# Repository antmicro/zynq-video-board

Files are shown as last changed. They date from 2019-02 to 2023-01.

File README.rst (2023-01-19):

================
Zynq Video Board
================

Copyright (c) 2018-2023 `Antmicro <https://www.antmicro.com>`_



Overview
========

This repository contains open hardware design files required to build the Zynq Video Board.
The board was designed as a custom carrier board for `Enclustra Mars SoC Modules <https://www.enclustra.com/en/products/system-on-chip-modules>`_.
It has been tested with `Mars ZX2 <https://www.enclustra.com/en/products/system-on-chip-modules/mars-zx2/>`_ and `Mars ZX3 <https://www.enclustra.com/en/products/system-on-chip-modules/mars-zx3/>`_ with the `Xilinx Zynq 70xx <https://www.xilinx.com/products/silicon-devices/soc/zynq-7000.html>`_ All Programmable SoC devices.

It can be used for interfacing MIPI CSI compatible image sensors.
It can also act as a simple evaluation kit for educational purposes.

Key features
============

* SO-DIMM connector supporting Enclustra Mars family
* Gigabit Ethernet RJ45 connector
* Micro SD connector
* USB 2.0 hub with two downstream ports exposed
* HDMI output interface
* Debug micro USB connector (supporting serial console and JTAG)
* JTAG connector supporting Xiling Platform Cable
* 2x MIPI CSI-2 camera interfaces (2 lanes) exposed on FPC connector
* onboard D-PHY receiver circuitry connected to the FPGA fabric
* 2x Digilent Pmod (TM) connectors for external accessories

The PCB project files were prepared in Altium Designer 14.1.

Getting started
===============

The board can be produced and assembled using the provided design files.
Please take a look at the mechanical layers for more information regarding the PCB stackup recommended for fabrication.
It is recommended to use a 12V 2A DC supply to power the board.
By default the device boots from an SD card.
The boot mode could be changed into booting from QSPI flash by removing the ``R7`` resistor and assembling ``R8``.

Preparing the software
----------------------

The Zynq Video Board is compatible with Enclustra Mars modules which are natively supported by the `Enclustra Build Environment <https://github.com/enclustra-bsp/bsp-xilinx>`_ (EBE) which is developed by Antmicro for Enclustra.
Please refer to the EBE documentation and Zynq Video Board schematics in order to prepare the software that could support your hardware configuration.
Also, please note that Mars ZX2 and Mars ZX3 differ in FPGA ball assignment so they require different constraint files for bitstream generation.

Debug UART connection
---------------------

Most of the debug messages are provided through the serial console.
The board is equipped with a multichannel FTDI chip offering both JTAG and UART interfaces to the host PC.
Please refer to the schematic sheets for more details.
After connecting the micro USB debug port to the host PC you should see four new ``/dev/ttyUSBx`` devices in your system.
The default debug UART channel is accessible through ``/dev/ttyUSB2`` (assuming that there are no other FTDI units connected to your PC).
The default baudrate for serial debug connection is 115200 baud with 8-bit transmission, 1 stop bit and with no flow control.

License
=======

`Apache-2.0 <LICENSE>`_

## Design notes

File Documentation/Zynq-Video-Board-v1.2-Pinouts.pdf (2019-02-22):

This document describes Zynq Video Board Rev.1.2 connectors' pinouts.

# General purpose buttons and LEDs

There are several buttons and LEDs which usage can be configured by the user. The table below shows their Mars ZX2 module and Zynq chip pin and ball assignment.

LED pin assignment

PCB desi gnator | ZX2 module pin (SO-DIMM) | ZX2 module signal name | Zynq-702 0 ball | FPGA pin name
LED1 | 44 | IO_B34_L8_W14_P | W14 | IO_L8P_34
LED2 | 46 | IO_B34_L8_Y14_N | Y14 | IO_L8N_34
LED3 | 48 | IO_B34_L6_P14_P | P14 | IO_L6P_34
LED4 | 50 | IO_B34_L6_VREF_R14_N | R14 | IO_L6N_VREF_34
LED5 | 54 | IO_B34_L5_T14_P | T14 | IO_L5P_34
LED6 | 56 | IO_B34_L5_T15_N | T15 | IO_L5N_34
LED7 | 69 | IO_B34_L22_W18_P | W18 | IO_L22P_34
LED8 | 71 | IO_B34_L22_W19_N | W19 | IO_L22N_34

General purpose buttons pin assignment

PCB desi gnator | ZX2 module pin (SO-DIMM) | ZX2 module signal name | Zynq-702 0 ball | FPGA pin name
SW1.U7 | 148 | IO_MIO48_B13_L11_SRCC_U7 | B12 | PS_MIO48
SW2.U10 | 152 | IO_MIO50_B13_L12_MRCC_T9 | B13 | PS_MIO50
SW3.V7 | 154 | IO_MIO51_B13_L12_U10 | B9 | PS_MIO51
SW4.T9 | 150 | IO_MIO49_B13_L11_V7 | C12 | PS_MIO49

Note: PCB button designators do not match Mars ZX2 signal names (see table).

# JTAG connector pinout

JTAG pin description

Signal name | Pin | Pin | Signal name
GND | 1 | 2 | +3V3
GND | 3 | 4 | JTAG_TMS
GND | 5 | 6 | JTAG_TCK
GND | 7 | 8 | JTAG_TDO
GND | 9 | 10 | JTAG_TDI
GND | 11 | 12 | NC
GND | 13 | 14 | SRST_RDYN

# Digilent Pmod connectors

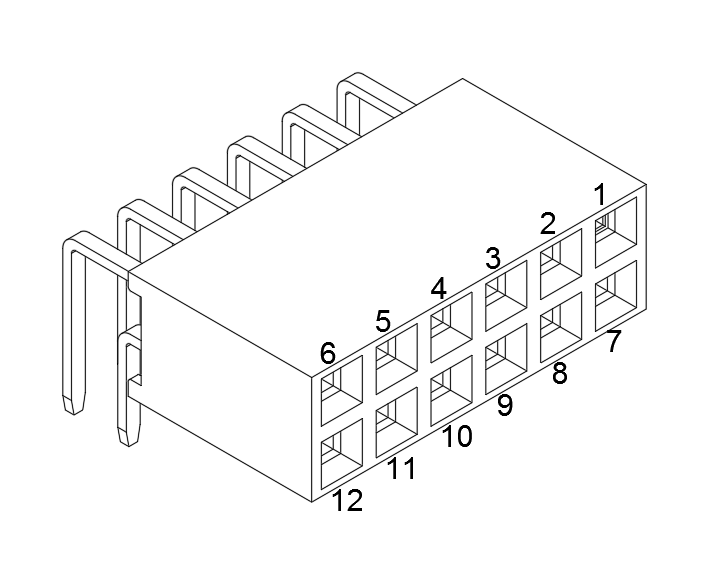
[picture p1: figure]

Digilent Pmod J6 connector pinout

Pin number | ZX2 module pin (SO-DIMM) | ZX2 module signal name | Zynq-70 20 ball | FPGA pin name
1 | 64 | IO_B34_L24_P15_P | P15 | IO_L24P_34
2 | 66 | IO_B34_L24_P16_N | P16 | IO_L24N_34
3 | 74 | IO_B34_L16_V20_P | V20 | IO_L16P_34
4 | 76 | IO_B34_L16_W20_N | W20 | IO_L16N_34
5 | GND | --- | --- | ---
6 | +3V3 | --- | --- | ---
7 | 68 | IO_B34_L23_N17_P | N17 | IO_L23P_34
8 | 70 | IO_B34_L23_P18_N | P18 | IO_L23N_34
9 | 78 | IO_B34_L15_T20_P | T20 | IO_L15P_34
10 | 80 | IO_B34_L15_U20_N | U20 | IO_L15N_34
11 | GND | --- | --- | ---
12 | +3V3 | --- | --- | ---

Digilent Pmod J7 connector pinout

Pin number | ZX2 module pin (SO-DIMM) | ZX2 module signal name | Zynq-70 20 ball | FPGA pin name
1 | 43 | IO_B34_L13_MRCC_N18_P | N18 | IO_L13P_MRCC_34
2 | 45 | IO_B34_L13_MRCC_P19_N | P19 | IO_L13N_MRCC_34
3 | 55 | IO_B34_L10_V15_P | V15 | IO_L10P_34
4 | 57 | IO_B34_L10_W15_N | W15 | IO_L10N_34
5 | GND | --- | --- | ---
6 | +3V3 | --- | --- | ---
7 | 49 | IO_B34_L14_SRCC_N20_P | N20 | IO_L14P_SRCC_34
8 | 51 | IO_B34_L14_SRCC_P20_N | P20 | IO_L14N_SRCC_34
9 | 59 | IO_B34_L7_Y16_P | Y16 | IO_L7P_34
10 | 61 | IO_B34_L7_Y17_N | Y17 | IO_L7N_34
11 | GND | --- | --- | ---
12 | +3V3 | --- | --- | ---

# MIPI-CSI connector pinout

The Zynq Video Board supports two 2-lane CSI-MIPI interfaces broken-out on FPC connector.

MIPI CSI connector pinout

Pin nu mber | ZVB signal name | ZX2 m odule pin (S O-DIM M) ZX2 module signal name | | Zynq-7 020 ball | FPGA pin name
1 | +5V0 | --- | --- | --- | ---
2 | +5V0 | --- | --- | --- | ---
3 | +3V3 | --- | --- | --- | ---
4 | +3V3 | --- | --- | --- | ---
5 | NC | --- | --- | --- | ---
6 | NC | --- | --- | --- | ---
7 | NC | --- | --- | --- | ---
8 | NC | --- | --- | --- | ---
9 | I2C_1_SCL_2V8 | 84 | IO_B35_L23_M14_P | M14 | IO_L23P_35
10 | I2C_1_SDA_2V8 | 86 | IO_B35_L23_M15_N | M15 | IO_L23N_35
11 | I2C_0_SCL_2V8 | 97 | IO_B35_L10_AD11_K19_P | K19 | IO_L10P_AD11P_35
12 | I2C_0_SDA_2V8 | 99 | IO_B35_L10_AD11_J19_N | J19 | IO_L10N_AD11N_35
13 | NC | --- | --- | --- | ---

14 | NC | --- | --- | --- | ---
15 | NC | --- | --- | --- | ---
16 | NC | --- | --- | --- | ---
17 | NC | --- | --- | --- | ---
18 | GPIO | 134 | IO_B35_L6_VREF_F17_N | F17 | IO_L6N_VREF_35
19 | NC | --- | --- | --- | ---
20 | NC | --- | --- | --- | ---
21 | GND | --- | --- | --- | ---
22 | CSI1_CLK_P | --- | --- | --- | ---
23 | CSI1_CLK_N | --- | --- | --- | ---
24 | GND | --- | --- | --- | ---
25 | CSI1_D0_P | --- | --- | --- | ---
26 | CSI1_D0_N | --- | --- | --- | ---
27 | CSI1_D1_P | --- | --- | --- | ---
28 | CSI1_D1_N | --- | --- | --- | ---
29 | NC | --- | --- | --- | ---
30 | NC | --- | --- | --- | ---
31 | NC | --- | --- | --- | ---
32 | NC | --- | --- | --- | ---
33 | GND | --- | --- | --- | ---
34 | NC | --- | --- | --- | ---
35 | NC | --- | --- | --- | ---
36 | GND | --- | --- | --- | ---
37 | NC | --- | --- | --- | ---
38 | NC | --- | --- | --- | ---
39 | GND | --- | --- | --- | ---
40 | CSI2_CLK_P | --- | --- | --- | ---
41 | CSI2_CLK_N | --- | --- | --- | ---
42 | GND | --- | --- | --- | ---
43 | CSI2_D0_P | --- | --- | --- | ---
44 | CSI2_D0_N | --- | --- | --- | ---
45 | CSI2_D1_P | --- | --- | --- | ---
46 | CSI2_D1_N | --- | --- | --- | ---
47 | NC | --- | --- | --- | ---
48 | NC | --- | --- | --- | ---
49 | NC | --- | --- | --- | ---
50 | NC | --- | --- | --- | ---

# Testpad list

Testpad list

Designator | | | Side | Description
GND | top | GND
TP1 | top | CAM1_PWDN signal
TP4 | top | CAM2_PWDN signal
TP5 | bottom | VOUT_1V8 signal
TP6 | bottom | Mars ZX2 SO-DIMM pin 123
TP7 | bottom | Mars ZX2 SO-DIMM pin 65
TP11 | bottom | GND

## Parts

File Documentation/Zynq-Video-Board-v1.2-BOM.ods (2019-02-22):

Bill of Materials
Project: | Zynq Video Board
Revision: | 1.2
Variant: | None
Creation Date: | 2/22/2019
Print Date: | 2019/02/22
Value | Footprint | Designator | Description | Manufacturer | Part Symbol | Quantity
2u2 | 0603 | C1 | MLCC SMT Capacitor 2u2F 0603 | TDK | C1608X5R1V225K080AC | 1
2u2 | 0603 | C2 | MLCC SMT Capacitor 2u2F 0603 | TDK | C1608X5R1V225K080AC | 1
100n | 0402 | C3 | MLCC SMT Capacitor 100nF 0402 | MULTICOMP | MC0402X104M100CT | 1
100n | 0402 | C4 | MLCC SMT Capacitor 100nF 0402 | MULTICOMP | MC0402X104M100CT | 1
2n2 | 0402 | C5 | MLCC SMT Capacitor 2n2 0402 | KEMET | C0402C222J3GACTU | 1
22u | 0805 | C6 | MLCC SMT Capacitor 22uF 0805 | MULTICOMP | MC0805X226M6R3CT | 1
22u | 0805 | C7 | MLCC SMT Capacitor 22uF 0805 | MULTICOMP | MC0805X226M6R3CT | 1
100n | 0402 | C11 | MLCC SMT Capacitor 100nF 0402 | MULTICOMP | MC0402X104M100CT | 1
100n | 0402 | C12 | MLCC SMT Capacitor 100nF 0402 | MULTICOMP | MC0402X104M100CT | 1
1n5 | 0402 | C13 | MLCC SMT Capacitor 1.5 nF 0402 | WURTH ELEKTRONIK | 885012205007 | 1
22u | 0805 | C14 | MLCC SMT Capacitor 22uF 0805 | MULTICOMP | MC0805X226M6R3CT | 1
22u | 0805 | C15 | MLCC SMT Capacitor 22uF 0805 | MULTICOMP | MC0805X226M6R3CT | 1
10n | 0402 | C16 | MLCC SMT Capacitor 10nF 0402 | AVX | 04025G103ZAT2A | 1
10n | 0402 | C17 | MLCC SMT Capacitor 10nF 0402 | AVX | 04025G103ZAT2A | 1
1u | 0603 | C18 | MLCC SMT Capacitor 1u 0603 | MULTICOMP | MC0603X105M6R3CT | 1
100n | 0402 | C19 | MLCC SMT Capacitor 100nF 0402 | MULTICOMP | MC0402X104M100CT | 1
100n | 0402 | C20 | MLCC SMT Capacitor 100nF 0402 | MULTICOMP | MC0402X104M100CT | 1
100n | 0402 | C21 | MLCC SMT Capacitor 100nF 0402 | MULTICOMP | MC0402X104M100CT | 1
22u | 0805 | C22 | MLCC SMT Capacitor 22uF 0805 | MULTICOMP | MC0805X226M6R3CT | 1
22u | 0805 | C23 | MLCC SMT Capacitor 22uF 0805 | MULTICOMP | MC0805X226M6R3CT | 1
100n | 0402 | C24 | MLCC SMT Capacitor 100nF 0402 | MULTICOMP | MC0402X104M100CT | 1
1u | 0603 | C25 | MLCC SMT Capacitor 1u 0603 | MULTICOMP | MC0603X105M6R3CT | 1
18p | 0402 | C26 | MLCC SMT Capacitor 18pF 0402 | KEMET | C0402C180J5GACAUTO | 1
18p | 0402 | C27 | MLCC SMT Capacitor 18pF 0402 | KEMET | C0402C180J5GACAUTO | 1
100n | 0402 | C28 | MLCC SMT Capacitor 100nF 0402 | MULTICOMP | MC0402X104M100CT | 1
100n | 0402 | C29 | MLCC SMT Capacitor 100nF 0402 | MULTICOMP | MC0402X104M100CT | 1
100n | 0402 | C30 | MLCC SMT Capacitor 100nF 0402 | MULTICOMP | MC0402X104M100CT | 1
100n | 0402 | C31 | MLCC SMT Capacitor 100nF 0402 | MULTICOMP | MC0402X104M100CT | 1
4u7 | 0603 | C32 | MLCC SMT Capacitor 4u7 0603 | MULTICOMP | MC0603X475K6R3CT | 1
100n | 0402 | C33 | MLCC SMT Capacitor 100nF 0402 | MULTICOMP | MC0402X104M100CT | 1
100n | 0402 | C34 | MLCC SMT Capacitor 100nF 0402 | MULTICOMP | MC0402X104M100CT | 1
100n | 0402 | C35 | MLCC SMT Capacitor 100nF 0402 | MULTICOMP | MC0402X104M100CT | 1
100n | 0402 | C37 | MLCC SMT Capacitor 100nF 0402 | MULTICOMP | MC0402X104M100CT | 1
100n | 0402 | C38 | MLCC SMT Capacitor 100nF 0402 | MULTICOMP | MC0402X104M100CT | 1
100n | 0402 | C39 | MLCC SMT Capacitor 100nF 0402 | MULTICOMP | MC0402X104M100CT | 1
4u7 | 0603 | C40 | MLCC SMT Capacitor 4u7 0603 | MULTICOMP | MC0603X475K6R3CT | 1
100n | 0402 | C41 | MLCC SMT Capacitor 100nF 0402 | MULTICOMP | MC0402X104M100CT | 1
100n | 0402 | C42 | MLCC SMT Capacitor 100nF 0402 | MULTICOMP | MC0402X104M100CT | 1
100n | 0402 | C43 | MLCC SMT Capacitor 100nF 0402 | MULTICOMP | MC0402X104M100CT | 1
4u7 | 0603 | C44 | MLCC SMT Capacitor 4u7 0603 | MULTICOMP | MC0603X475K6R3CT | 1
100n | 0402 | C45 | MLCC SMT Capacitor 100nF 0402 | MULTICOMP | MC0402X104M100CT | 1
18p | 0402 | C46 | MLCC SMT Capacitor 18pF 0402 | KEMET | C0402C180J5GACAUTO | 1
18p | 0402 | C47 | MLCC SMT Capacitor 18pF 0402 | KEMET | C0402C180J5GACAUTO | 1
100n | 0402 | C48 | MLCC SMT Capacitor 100nF 0402 | MULTICOMP | MC0402X104M100CT | 1
100n | 0402 | C49 | MLCC SMT Capacitor 100nF 0402 | MULTICOMP | MC0402X104M100CT | 1
1u | 0603 | C50 | MLCC SMT Capacitor 1u 0603 | MULTICOMP | MC0603X105M6R3CT | 1
100n | 0402 | C51 | MLCC SMT Capacitor 100nF 0402 | MULTICOMP | MC0402X104M100CT | 1
100n | 0402 | C52 | MLCC SMT Capacitor 100nF 0402 | MULTICOMP | MC0402X104M100CT | 1
1u | 0603 | C53 | MLCC SMT Capacitor 1u 0603 | MULTICOMP | MC0603X105M6R3CT | 1
100n | 0402 | C54 | MLCC SMT Capacitor 100nF 0402 | MULTICOMP | MC0402X104M100CT | 1
1u | 0603 | C55 | MLCC SMT Capacitor 1u 0603 | MULTICOMP | MC0603X105M6R3CT | 1
100n | 0402 | C56 | MLCC SMT Capacitor 100nF 0402 | MULTICOMP | MC0402X104M100CT | 1
100n | 0402 | C57 | MLCC SMT Capacitor 100nF 0402 | MULTICOMP | MC0402X104M100CT | 1
2u2 | 0603 | C58 | MLCC SMT Capacitor 2u2F 0603 | TDK | C1608X5R1V225K080AC | 1
SMAJ12A | DO-214AA | D1 | DIODE, TVS, 12V, 400W | BOURNS | SMAJ12A | 1
1N4148WS | SOD-323 | D2 | Diode small signal | ON SEMICONDUCTOR | 1N4148WS | 1
BAV70LT3G | SOT-23 | D3 | Dual switching diode, common cathode | ON SEMICONDUCTOR | BAV70LT3G | 1
TPD2E009DRTR | SOT-3 | D4 | ESD Suppressors 2-CH | TEXAS INSTRUMENTS | TPD2E009DRTR | 1
TPD6E05U06 | TPD6E05U06_PASS | D5 | ESD Suppressors 6-CH Pass through layout | TEXAS INSTRUMENTS | TPD6E05U06RVZR | 1
TPD4E05U06 | TPD4E05U06_PASS | D7 | ESD Suppressors 4-CH | TEXAS INSTRUMENTS | TPD4E05U06DQAR | 1
TPD4E05U06 | TPD4E05U06_PASS | D9 | ESD Suppressors 4-CH | TEXAS INSTRUMENTS | TPD4E05U06DQAR | 1
TPD4E05U06 | TPD4E05U06_PASS | D10 | ESD Suppressors 4-CH | TEXAS INSTRUMENTS | TPD4E05U06DQAR | 1
TPD4E05U06 | TPD4E05U06_PASS | D11 | ESD Suppressors 4-CH | TEXAS INSTRUMENTS | TPD4E05U06DQAR | 1
TPD6E05U06 | TPD6E05U06_PASS | D12 | ESD Suppressors 6-CH Pass through layout | TEXAS INSTRUMENTS | TPD6E05U06RVZR | 1
KPT-1608SGC | LED0603 | D13 | LED Green 0603 case | KINGBRIGHT | KPT-1608SGC | 1
KPT-1608SGC | LED0603 | DBG | LED Green 0603 case | KINGBRIGHT | KPT-1608SGC | 1
3A | 0603 | F1 | Fuse, Surface Mount, SinglFuse SF-0603FP Series, 3 A, 32 VDC, Fast Acting, 0603 | BOURNS | SF-0603FP300-2 | 1
MX-22-23-2021 | molex_2223-2021 | FAN | Pinhead connector with key | MOLEX | 022232021 A-6373-02A222 | 1
TLV73328PDBVT | SOT23-5N | IC1 | Capacitor-Free, 300-mA, Low-Dropout Regulator with Foldback Current Limit for Portable Devices | TEXAS INSTRUMENTS | TLV73328PDBVT | 1
NCP3170BDR2G | SOIC-8 | IC2 | DC-DC buck (step-down), reg., 4.5V-18Vin, Vou 1.25V-5V/3A, 1 MHz, SOIC-8 | ON SEMICONDUCTOR | NCP3170BDR2G | 1
NCP3170BDR2G | SOIC-8 | IC4 | DC-DC buck (step-down), reg., 4.5V-18Vin, Vou 1.25V-5V/3A, 1 MHz, SOIC-8 | ON SEMICONDUCTOR | NCP3170BDR2G | 1
MIC2026-1YM | SOIC-8 | IC5 | Power Load Distribution Switch IC, Active High, 2 Outputs, 5.5 V in, 900 mA, 0.09 ohm, SOIC-8 | MICROCHIP | MIC2026-1YM | 1
USB2422 | QFN24 | IC6 | The USB2422-I/MJ is a 2-port USB 2.0 high-speed Hub Controller IC with two downstream ports for embedded USB solutions. | MICROCHIP | USB2422-I/MJ | 1
TPD12S016PWR | TSOP65P640X120-24L | IC7 | TPD12S016PWR is a single-chip High Definition Multimedia Interface (HDMI) | TEXAS INSTRUMENTS | TPD12S016PWR | 1
FT4232HQ | FT2232HQ | IC8 | FTDI FT4232HQ-R Interface Bridges, USB to UART, MPSSE, 1.62 V, 1.98 V, QFN, 64 Pins, -40 °C | FTDI | FT4232HQ-R | 1
NTB0104BQ | DHVQFN14 | IC9 | 4 bit voltage level translator - no pullups | NXP | NTB0104BQ | 1
NTB0104BQ | DHVQFN14 | IC10 | 4 bit voltage level translator - no pullups | NXP | NTB0104BQ | 1
NTB0104BQ | DHVQFN14 | IC11 | 4 bit voltage level translator - no pullups | NXP | NTB0104BQ | 1
NTS0104BQ | DHVQFN14 | IC12 | 4 bit voltage level translator - pullups | NXP | NTS0104BQ | 1
TCA9554A | DBQ0016A | IC13 | Remote 8bit I2C SMBus I/O expander | TEXAS INSTRUMENTS | TCA9554A | 1
RM24C128DS-LTAI-B | TSSOP-8 | IC14 | EEPROM with UID and OTP registers. | Adesto | RM24C128DS-LTAI-B | 1
TLV73333PDBVT | SOT23-5N | IC15 | Capacitor-Free, 300-mA, Low-Dropout Regulator with Foldback Current Limit for Portable Devices | TEXAS INSTRUMENTS | TLV73328PDBVT | 1
6A | 1101M2S3AQE2 | J1 | single-pole double-throw (SPDT) PC mount vertical Miniature Slide Switch with right angle through-hole termination | C&K | 1101M2S3AQE2 | 1
 | DC_SOCKET | J2 |  | MULTICOMP | MJ-179PH | 1
 | T_MMMC_896-43-008-90-000000 | J3 | 8-way 2-port USB 2.0 type-A Stacked Connector with gold-plated copper alloy contacts. | AMPHENOL | 72309-8014BLF | 1
68715014522 | 68715014522_FLIPPED | J5 | 0.50mm SMT ZIF Horizontal Bottom Contact WR-FPC | WURTH ELEKTRONIK | 68715014522 | 1
SSW-106-02-G-D-RA | SSW-106-02-G-D-RA | J6 | Board-To-Board Connector, Right Angle, 2.54 mm, 12 Contacts, Receptacle, SSW Series, Through Hole | SAMTEC | SSW-106-02-G-D-RA | 1
SSW-106-02-G-D-RA | SSW-106-02-G-D-RA | J7 | Board-To-Board Connector, Right Angle, 2.54 mm, 12 Contacts, Receptacle, SSW Series, Through Hole | SAMTEC | SSW-106-02-G-D-RA | 1
114-00841-68 | 114-00841-68 | J9 | Micro SD card holder | AMPHENOL | 114-00841-68 | 1
7499111121A | WE_7499111121A | J10 | CONN MAGJACK 1PORT 1000 BASE-T | WURTH ELEKTRONIK | 7499111121A | 1
47151-1001 | Molex_HDMI_471511001 | J11 | Header right angle HDMI | MOLEX | 47151-1001 | 1
Molex-87831-1420 | CON-Molex-87831-1420 | J12 | HEADER, SQUARE PIN, M/GRID, 14WAY | MOLEX | 87831-1420 | 1
 | WE_629105150521 | J13 | Micro USB B | WURTH ELEKTRONIK | 629105150521 | 1
BLM18SG121TN1D | 0603 | L1 | FERRITE BEAD, 0.025OHM, 3A, 0603 | MURATA | BLM18SG121TN1D | 1
IHLP2525CZER3R3M01 | IHLP-2525CZ-01 | L2 | 3.3 µH, ± 20%, Shielded, 0.02 ohm, 8 A | VISHAY | IHLP2525CZER3R3M01 | 1
BLM18SG121TN1D | 0603 | L3 | FERRITE BEAD, 0.025OHM, 3A, 0603 | MURATA | BLM18SG121TN1D | 1
BLM18SG121TN1D | 0603 | L4 | FERRITE BEAD, 0.025OHM, 3A, 0603 | MURATA | BLM18SG121TN1D | 1
IHLP2525CZER3R3M01 | IHLP-2525CZ-01 | L5 | 3.3 µH, ± 20%, Shielded, 0.02 ohm, 8 A | VISHAY | IHLP2525CZER3R3M01 | 1
BLM18SG121TN1D | 0603 | L6 | FERRITE BEAD, 0.025OHM, 3A, 0603 | MURATA | BLM18SG121TN1D | 1
BLM18SG121TN1D | 0603 | L7 | FERRITE BEAD, 0.025OHM, 3A, 0603 | MURATA | BLM18SG121TN1D | 1
DLW21SN900SQ2 | DLW21SN900SQ2 | L8 | Common mode choke | MURATA | DLW21SN900SQ2L | 1
DLW21SN900SQ2 | DLW21SN900SQ2 | L9 | Common mode choke | MURATA | DLW21SN900SQ2L | 1
BLM18SG121TN1D | 0603 | L10 | FERRITE BEAD, 0.025OHM, 3A, 0603 | MURATA | BLM18SG121TN1D | 1
BLM18AG601SN1D | 0603 | L11 | FERRITE BEAD, 0.38OHM, 0.5, 0603 | MURATA | BLM18SG121TN1D | 1
BLM18SG121TN1D | 0603 | L13 | FERRITE BEAD, 0.025OHM, 3A, 0603 | MURATA | BLM18SG121TN1D | 1
DLW21SN900SQ2 | DLW21SN900SQ2 | L14 | Common mode choke | MURATA | DLW21SN900SQ2L | 1
BLM18AG601SN1D | 0603 | L15 | FERRITE BEAD, 0.38OHM, 0.5, 0603 | MURATA | BLM18SG121TN1D | 1
KPT-1608SGC | LED0603 | LED1 | LED Green 0603 case | KINGBRIGHT | KPT-1608SGC | 1
KPT-1608SGC | LED0603 | LED2 | LED Green 0603 case | KINGBRIGHT | KPT-1608SGC | 1
KPT-1608SGC | LED0603 | LED3 | LED Green 0603 case | KINGBRIGHT | KPT-1608SGC | 1
KPT-1608SGC | LED0603 | LED4 | LED Green 0603 case | KINGBRIGHT | KPT-1608SGC | 1
KPT-1608SGC | LED0603 | LED5 | LED Green 0603 case | KINGBRIGHT | KPT-1608SGC | 1
KPT-1608SGC | LED0603 | LED6 | LED Green 0603 case | KINGBRIGHT | KPT-1608SGC | 1
KPT-1608SGC | LED0603 | LED7 | LED Green 0603 case | KINGBRIGHT | KPT-1608SGC | 1
KPT-1608SGC | LED0603 | LED8 | LED Green 0603 case | KINGBRIGHT | KPT-1608SGC | 1
1565917-4 | TE_1565917-4 | M1 | SODIMM Connector 200_1V8 | TE | 1565917-4 | 1
KPT-1608SGC | LED0603 | PWR_LED | LED Green 0603 case | KINGBRIGHT | KPT-1608SGC | 1
PMV32UP | SOT-23 | Q1 | P CH, 20V, 4A | NXP | PMV32UP | 1
BSS138PW | SC70-3 | Q2 | MOSFET, N CH, 60V, 0.2A | NXP | BSS138PW | 1
BSS138PW | SC70-3 | Q3 | MOSFET, N CH, 60V, 0.2A | NXP | BSS138PW | 1
1k2 | 0402 | R1 | SMT Resistor 1k2 0402 | PANASONIC | ERJ2RKF1201X | 1
0R | 0603 | R2 | SMT Resistor 0R 0603 | BOURNS | CR0603-J/-000ELF | 1
0R | 0603 | R3 | SMT Resistor 0R 0603 | BOURNS | CR0603-J/-000ELF | 1
24k9 | 0402 | R4 | SMT Resistor 24k9 0402 | WALSIN | WR04X2492FTL | 1
2k2 | 0402 | R5 | SMT Resistor 4k7 0402 | PANASONIC ELECTRONIC COMPONENTS | ERJ2GEJ472X | 1
8k25 | 0402 | R6 | SMT Resistor 8k25 0402 | PANASONIC | ERJ2RKF8251X | 1
0R | 0402 | R7 | SMT Resistor 0R 0402 | MULTICOMP | MCMR04X000 PTL | 1
0R | 0402 | R8 | SMT Resistor 0R 0402 | MULTICOMP | MCMR04X000 PTL | 1
0R | 0603 | R9 | SMT Resistor 0R 0603 | BOURNS | CR0603-J/-000ELF | 1
10k | 0402 | R10 | SMT Resistor 10k 0402 | MULTICOMP | MCMR04X1002FTL | 1
24k9 | 0402 | R11 | SMT Resistor 24k9 0402 | WALSIN | WR04X2492FTL | 1
7k87 | 0402 | R12 | SMT Resistor 7k87 0402 | MULTICOMP | MCMR04X7871FTL | 1
12k | 0402 | R13 | SMT Resistor 12k 0402 | VISHAY | CRCW040212K0FKEDHP | 1
10k | 0402 | R14 | SMT Resistor 10k 0402 | MULTICOMP | MCMR04X1002FTL | 1
10k | 0402 | R15 | SMT Resistor 10k 0402 | MULTICOMP | MCMR04X1002FTL | 1
10k | 0402 | R16 | SMT Resistor 10k 0402 | MULTICOMP | MCMR04X1002FTL | 1
12k | 0402 | R17 | SMT Resistor 12k 0402 | VISHAY | CRCW040212K0FKEDHP | 1
10k | 0402 | R18 | SMT Resistor 10k 0402 | MULTICOMP | MCMR04X1002FTL | 1
10k | 0402 | R19 | SMT Resistor 10k 0402 | MULTICOMP | MCMR04X1002FTL | 1
0R | 0402 | R20 | SMT Resistor 0R 0402 | MULTICOMP | MCMR04X000 PTL | 1
100R | 0402 | R25 | SMT Resistor 100R 0402 | BOURNS | CR0402-FX-1000GLF | 1
150R | 0402 | R26 | SMT Resistor 150R_0402 | VISHAY | CRCW0402150RFKED | 1
10k | 0402 | R27 | SMT Resistor 10k 0402 | MULTICOMP | MCMR04X1002FTL | 1
100R | 0402 | R28 | SMT Resistor 100R 0402 | BOURNS | CR0402-FX-1000GLF | 1
10k | 0402 | R29 | SMT Resistor 10k 0402 | MULTICOMP | MCMR04X1002FTL | 1
10k | 0402 | R30 | SMT Resistor 10k 0402 | MULTICOMP | MCMR04X1002FTL | 1
470R | 0402 | R31 | SMT Resistor 470R 0402 | VISHAY | CRCW0402470RFKED | 1
22R | 0402 | R32 | SMT Resistor 22R 0402 | VISHAY | CRCW040222R0FKED | 1
22R | 0402 | R33 | SMT Resistor 22R 0402 | VISHAY | CRCW040222R0FKED | 1
22R | 0402 | R34 | SMT Resistor 22R 0402 | VISHAY | CRCW040222R0FKED | 1
22R | 0402 | R35 | SMT Resistor 22R 0402 | VISHAY | CRCW040222R0FKED | 1
22R | 0402 | R36 | SMT Resistor 22R 0402 | VISHAY | CRCW040222R0FKED | 1
10k | 0402 | R37 | SMT Resistor 10k 0402 | MULTICOMP | MCMR04X1002FTL | 1
12k | 0402 | R38 | SMT Resistor 12k 0402 | VISHAY | CRCW040212K0FKEDHP | 1
100R | 0402 | R39 | SMT Resistor 100R 0402 | BOURNS | CR0402-FX-1000GLF | 1
100R | 0402 | R40 | SMT Resistor 100R 0402 | BOURNS | CR0402-FX-1000GLF | 1
150R | 0402 | R41 | SMT Resistor 150R_0402 | VISHAY | CRCW0402150RFKED | 1
150R | 0402 | R42 | SMT Resistor 150R_0402 | VISHAY | CRCW0402150RFKED | 1
100R | 0402 | R43 | SMT Resistor 100R 0402 | BOURNS | CR0402-FX-1000GLF | 1
100R | 0402 | R44 | SMT Resistor 100R 0402 | BOURNS | CR0402-FX-1000GLF | 1
100R | 0402 | R45 | SMT Resistor 100R 0402 | BOURNS | CR0402-FX-1000GLF | 1
100R | 0402 | R46 | SMT Resistor 100R 0402 | BOURNS | CR0402-FX-1000GLF | 1
150R | 0402 | R47 | SMT Resistor 150R_0402 | VISHAY | CRCW0402150RFKED | 1
150R | 0402 | R48 | SMT Resistor 150R_0402 | VISHAY | CRCW0402150RFKED | 1
100R | 0402 | R49 | SMT Resistor 100R 0402 | BOURNS | CR0402-FX-1000GLF | 1
100R | 0402 | R50 | SMT Resistor 100R 0402 | BOURNS | CR0402-FX-1000GLF | 1
10k | 0402 | R51 | SMT Resistor 10k 0402 | MULTICOMP | MCMR04X1002FTL | 1
10k | 0402 | R52 | SMT Resistor 10k 0402 | MULTICOMP | MCMR04X1002FTL | 1
10k | 0402 | R53 | SMT Resistor 10k 0402 | MULTICOMP | MCMR04X1002FTL | 1
10k | 0402 | R54 | SMT Resistor 10k 0402 | MULTICOMP | MCMR04X1002FTL | 1
22R | 0402 | R55 | SMT Resistor 22R 0402 | VISHAY | CRCW040222R0FKED | 1
22R | 0402 | R56 | SMT Resistor 22R 0402 | VISHAY | CRCW040222R0FKED | 1
22R | 0402 | R57 | SMT Resistor 22R 0402 | VISHAY | CRCW040222R0FKED | 1
22R | 0402 | R58 | SMT Resistor 22R 0402 | VISHAY | CRCW040222R0FKED | 1
8x330R | R_ARRAY_0402 | R59 | SMD Resistors Array 0402 | PANASONIC | EXB2HV331JV | 1
150R | 0402 | R60 | SMT Resistor 150R_0402 | VISHAY | CRCW0402150RFKED | 1
150R | 0402 | R61 | SMT Resistor 150R_0402 | VISHAY | CRCW0402150RFKED | 1
10k | 0402 | R62 | SMT Resistor 10k 0402 | MULTICOMP | MCMR04X1002FTL | 1
10k | 0402 | R63 | SMT Resistor 10k 0402 | MULTICOMP | MCMR04X1002FTL | 1
10k | 0402 | R64 | SMT Resistor 10k 0402 | MULTICOMP | MCMR04X1002FTL | 1
10k | 0402 | R65 | SMT Resistor 10k 0402 | MULTICOMP | MCMR04X1002FTL | 1
10k | 0402 | R66 | SMT Resistor 10k 0402 | MULTICOMP | MCMR04X1002FTL | 1
10k | 0402 | R67 | SMT Resistor 10k 0402 | MULTICOMP | MCMR04X1002FTL | 1
10k | 0402 | R68 | SMT Resistor 10k 0402 | MULTICOMP | MCMR04X1002FTL | 1
330R | 0402 | R69 | SMT Resistor 330R 0402 | MULTICOMP | MCMR04X3300FTL | 1
49R9 | 0402 | R70 | SMT Resistor 49R9 0402 | VISHAY | CRCW040249R9FKED | 1
49R9 | 0402 | R71 | SMT Resistor 49R9 0402 | VISHAY | CRCW040249R9FKED | 1
49R9 | 0402 | R72 | SMT Resistor 49R9 0402 | VISHAY | CRCW040249R9FKED | 1
49R9 | 0402 | R73 | SMT Resistor 49R9 0402 | VISHAY | CRCW040249R9FKED | 1
49R9 | 0402 | R74 | SMT Resistor 49R9 0402 | VISHAY | CRCW040249R9FKED | 1
49R9 | 0402 | R75 | SMT Resistor 49R9 0402 | VISHAY | CRCW040249R9FKED | 1
49R9 | 0402 | R76 | SMT Resistor 49R9 0402 | VISHAY | CRCW040249R9FKED | 1
49R9 | 0402 | R77 | SMT Resistor 49R9 0402 | VISHAY | CRCW040249R9FKED | 1
10k | 0402 | R78 | SMT Resistor 10k 0402 | MULTICOMP | MCMR04X1002FTL | 1
10k | 0402 | R79 | SMT Resistor 10k 0402 | MULTICOMP | MCMR04X1002FTL | 1
330R | 0402 | R80 | SMT Resistor 330R 0402 | MULTICOMP | MCMR04X3300FTL | 1
2k2 | 0402 | R81 | SMT Resistor 2k2 0402 | MULTICOMP | MCWR04X2201FTL | 1
2k2 | 0402 | R82 | SMT Resistor 2k2 0402 | MULTICOMP | MCWR04X2201FTL | 1
2k2 | 0402 | R83 | SMT Resistor 2k2 0402 | MULTICOMP | MCWR04X2201FTL | 1
0R | 0402 | R84 | SMT Resistor 0R 0402 | MULTICOMP | MCMR04X000 PTL | 1
0R | 0402 | R85 | SMT Resistor 0R 0402 | MULTICOMP | MCMR04X000 PTL | 1
10k | 0402 | R86 | SMT Resistor 10k 0402 | MULTICOMP | MCMR04X1002FTL | 1
10k | 0402 | R87 | SMT Resistor 10k 0402 | MULTICOMP | MCMR04X1002FTL | 1
10k | 0402 | R88 | SMT Resistor 10k 0402 | MULTICOMP | MCMR04X1002FTL | 1
10k | 0402 | R89 | SMT Resistor 10k 0402 | MULTICOMP | MCMR04X1002FTL | 1
10k | 0402 | R90 | SMT Resistor 10k 0402 | MULTICOMP | MCMR04X1002FTL | 1
10k | 0402 | R91 | SMT Resistor 10k 0402 | MULTICOMP | MCMR04X1002FTL | 1
10k | 0402 | R92 | SMT Resistor 10k 0402 | MULTICOMP | MCMR04X1002FTL | 1
10k | 0402 | R93 | SMT Resistor 10k 0402 | MULTICOMP | MCMR04X1002FTL | 1
9k1 | 0402 | R94 | SMT Resistor 9k1 0402 | YAGEO | RC0402FR-079K1L | 1
0R | 0402 | R95 | SMT Resistor 0R 0402 | MULTICOMP | MCMR04X000 PTL | 1
100R | 0402 | R96 | SMT Resistor 100R 0402 | BOURNS | CR0402-FX-1000GLF | 1
150R | 0402 | R97 | SMT Resistor 150R_0402 | VISHAY | CRCW0402150RFKED | 1
100R | 0402 | R98 | SMT Resistor 100R 0402 | BOURNS | CR0402-FX-1000GLF | 1
9774030243 | M2-3mm | SP1 | M2x3 | WURTH ELEKTRONIK | 9774030243 | 1
9774030243 | M2-3mm | SP2 | M2x3 | WURTH ELEKTRONIK | 9774030243 | 1
B3S-1002 | B3S-100X | SW1 | Tactile switch | OMRON | B3S-1002 | 1
B3S-1002 | B3S-100X | SW2 | Tactile switch | OMRON | B3S-1002 | 1
B3S-100X | B3S-100X | SW3 | Tactile switch | OMRON | B3S-1002 | 1
B3S-100X | B3S-100X | SW4 | Tactile switch | OMRON | B3S-1002 | 1
B3S-100X | B3S-100X | SW5 | Tactile switch | OMRON | B3S-1002 | 1
B3S-100X | B3S-100X | SW6 | Tactile switch | OMRON | B3S-1002 | 1
24MHz | X1E0000210832 | Y1 | Crystal, 24 MHz, SMD, 3.2mm x 2.5mm, 10 ppm, 18 pF, 10 ppm, TSX-3225 Series | EPSON | X1E0000210832 TSX-3225 24MHZ | 1
12MHz | QC3CA12 | Y2 | Crystal, 12 MHz, SMD, 3.2mm x 2.5mm, 30 ppm, 12 pF | QANTEK TECHNOLOGY CORPORATION | QC3CA12.0000F12B23M | 1
 |  |  |  |  |  | 224
Approved | Notes

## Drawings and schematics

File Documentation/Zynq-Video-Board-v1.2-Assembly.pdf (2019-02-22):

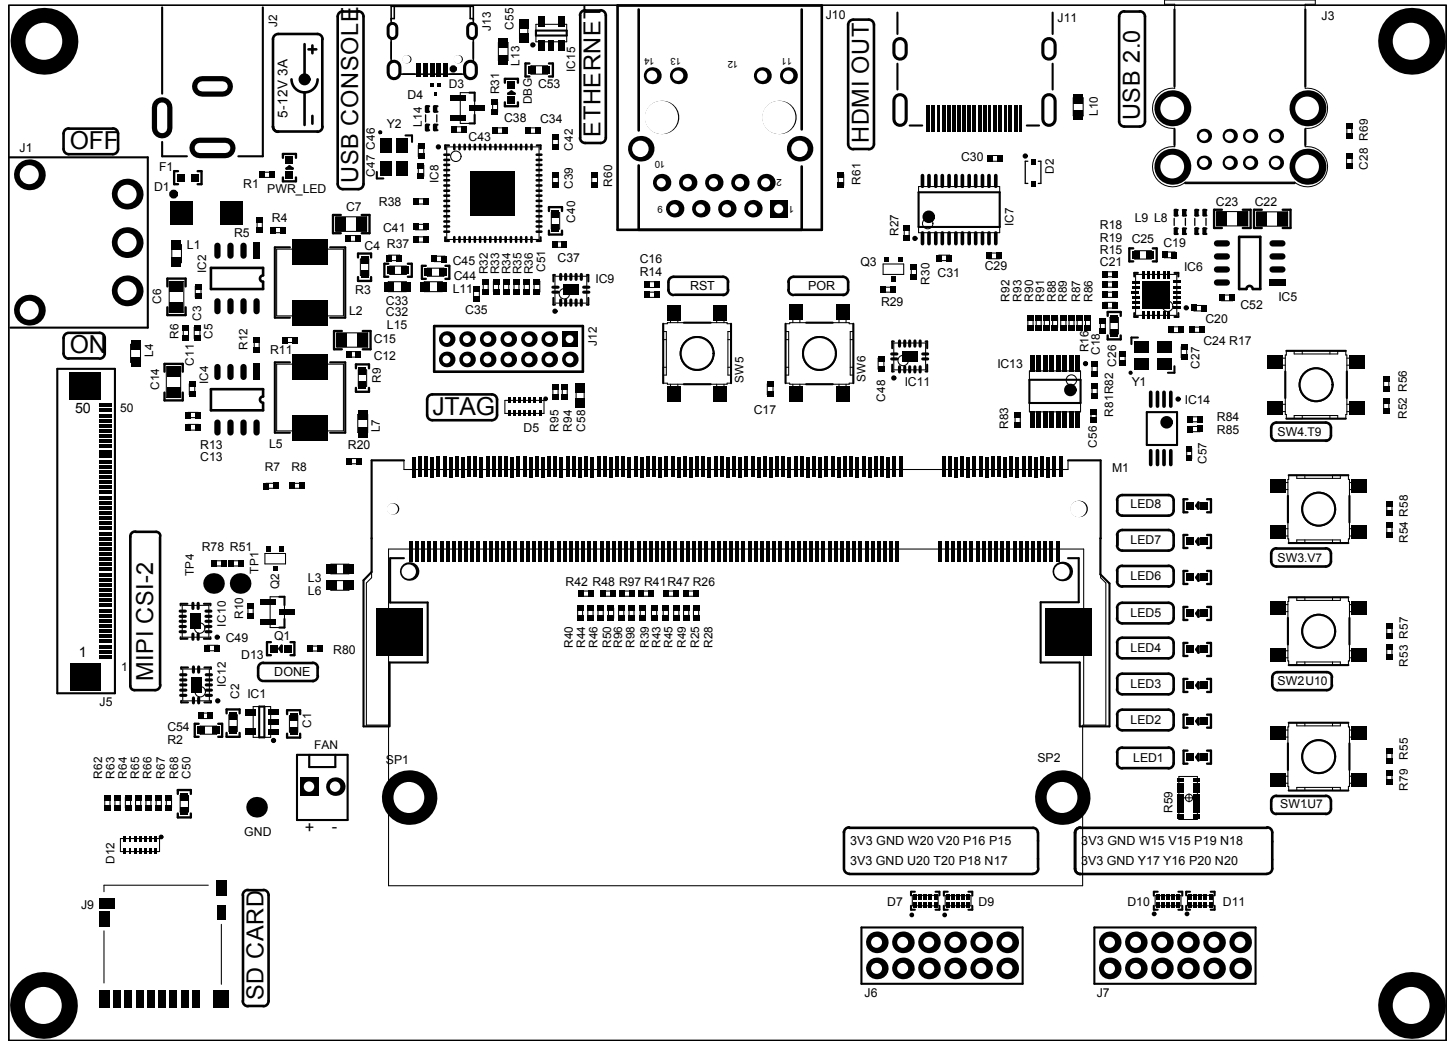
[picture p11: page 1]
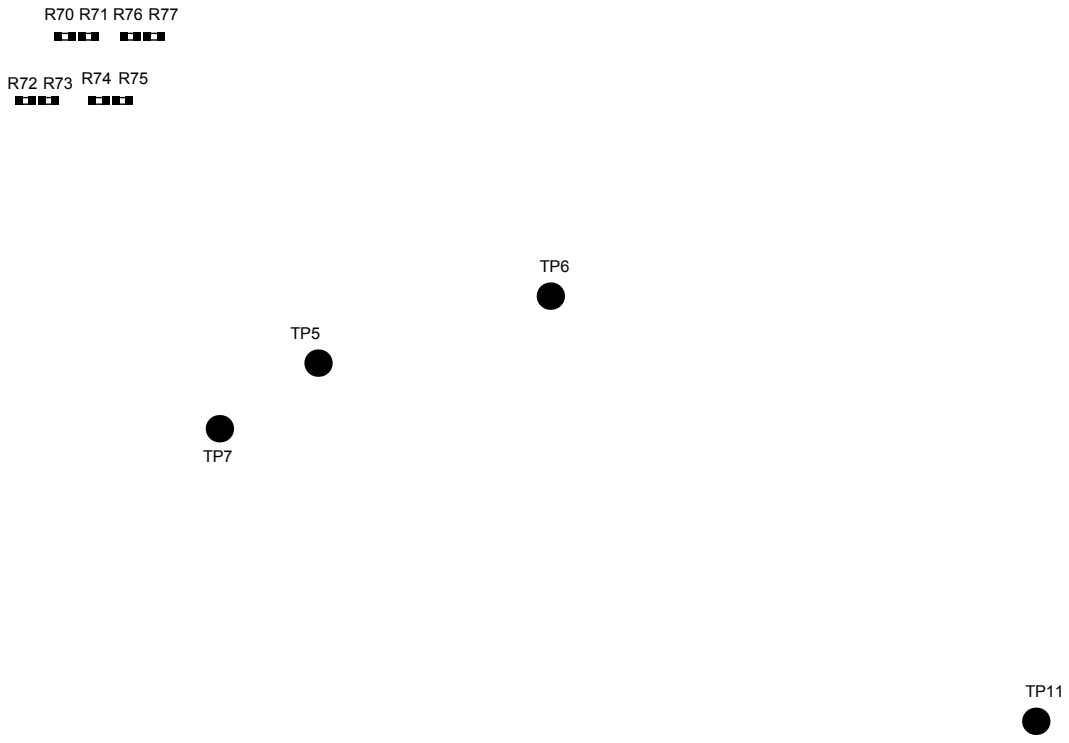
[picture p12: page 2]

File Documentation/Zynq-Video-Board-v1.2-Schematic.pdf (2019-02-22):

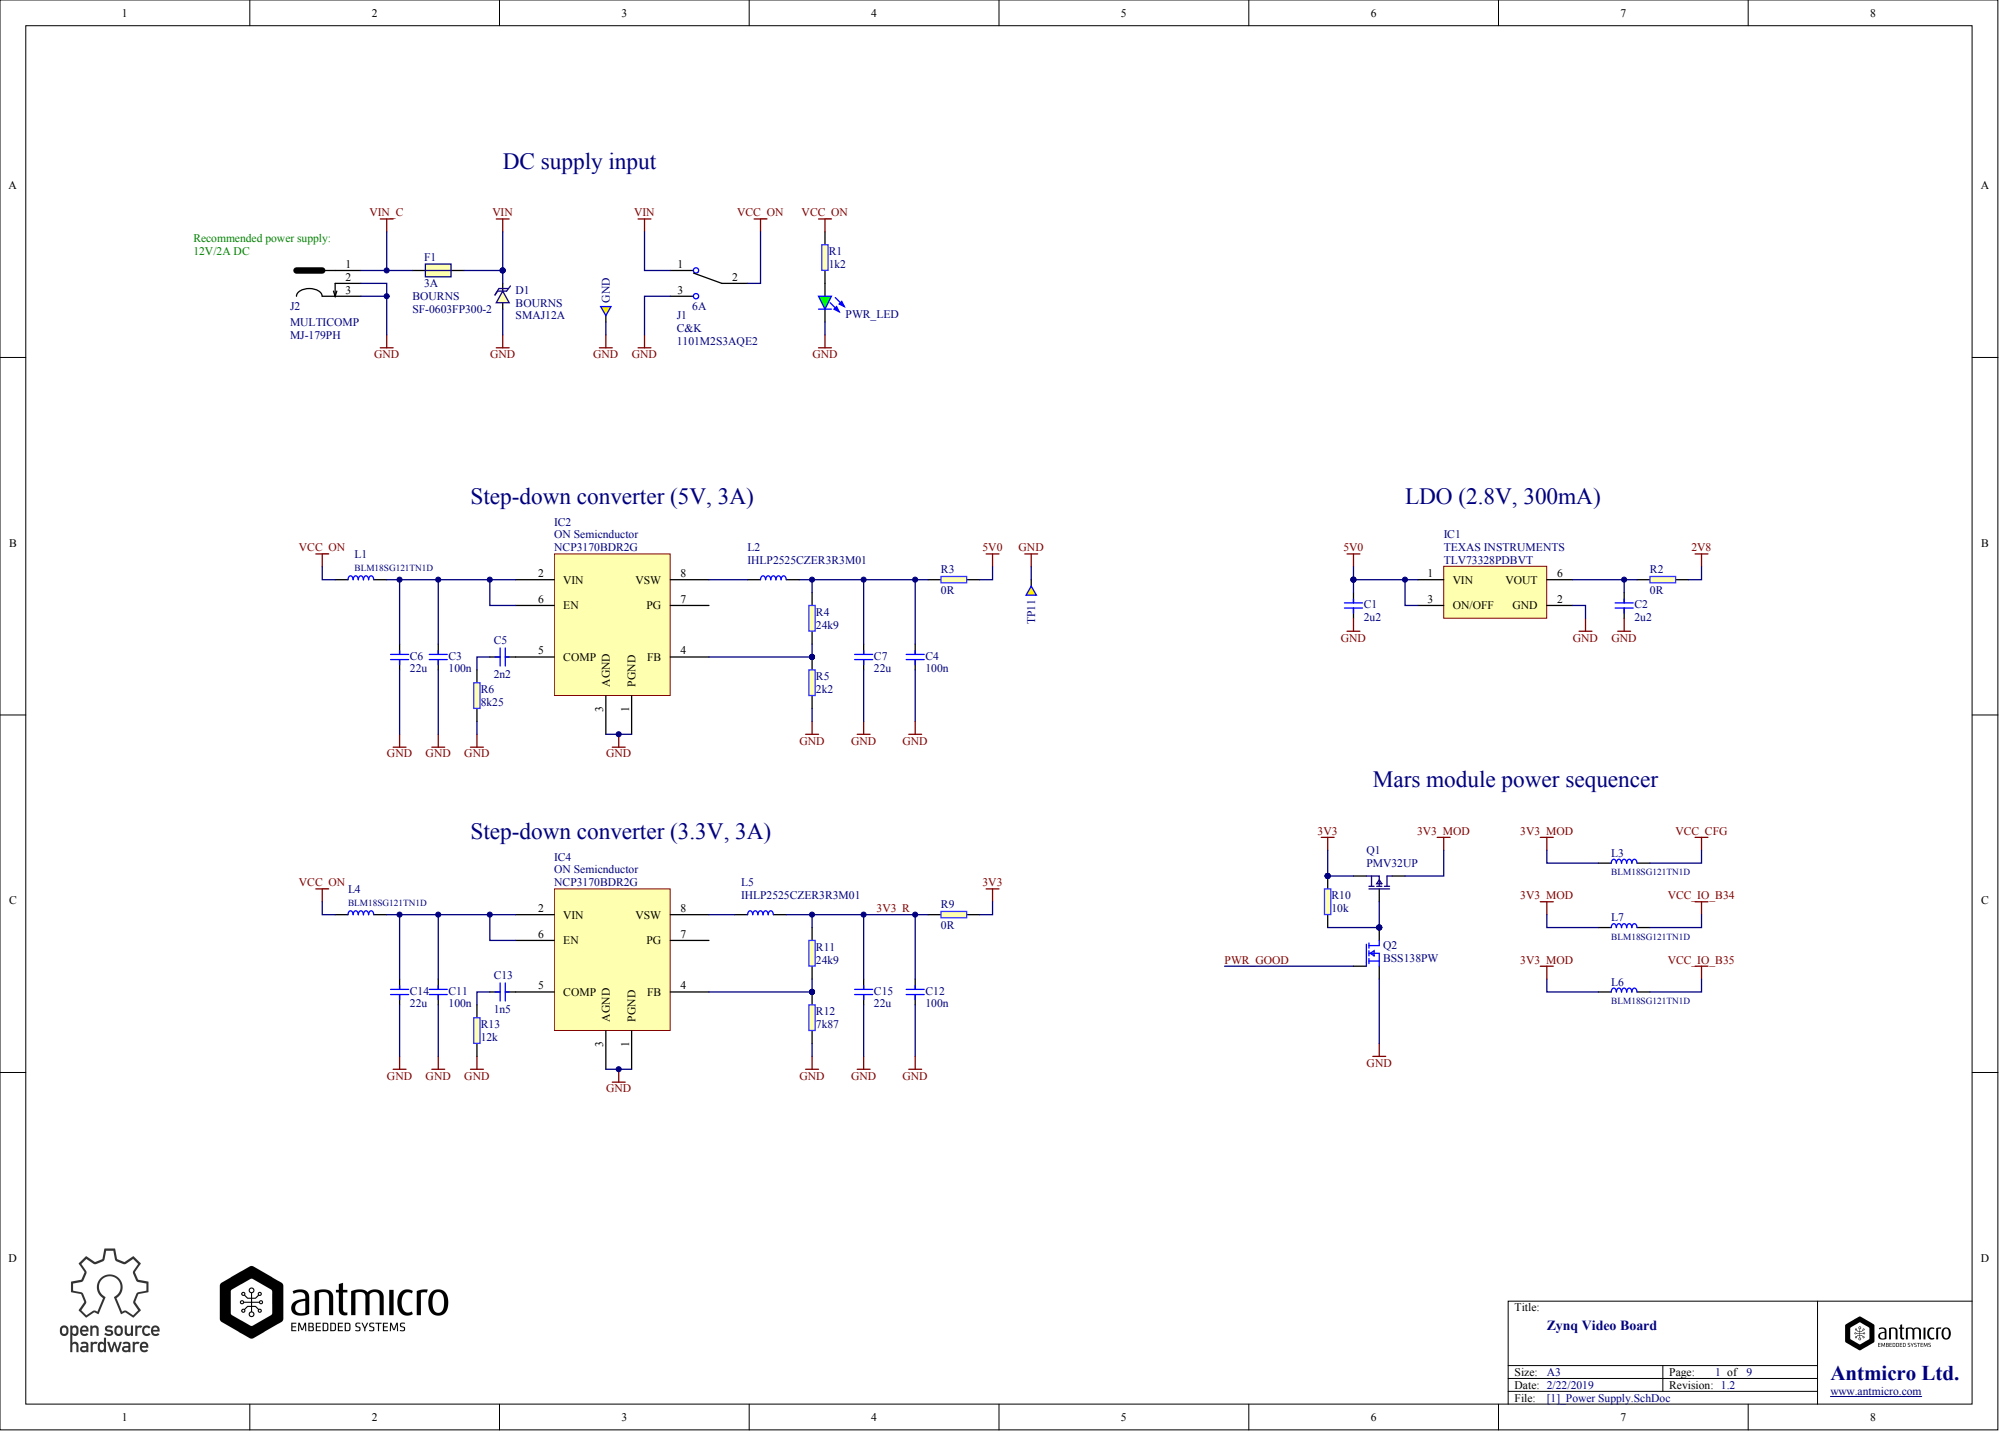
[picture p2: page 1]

Mars module power sequencer

Title: Zynq Video Board | Antmicro Ltd. www.antmicro.com

Size: A3 | Page: 1 of 9
Date: 2/22/2019 | Revision: 1.2

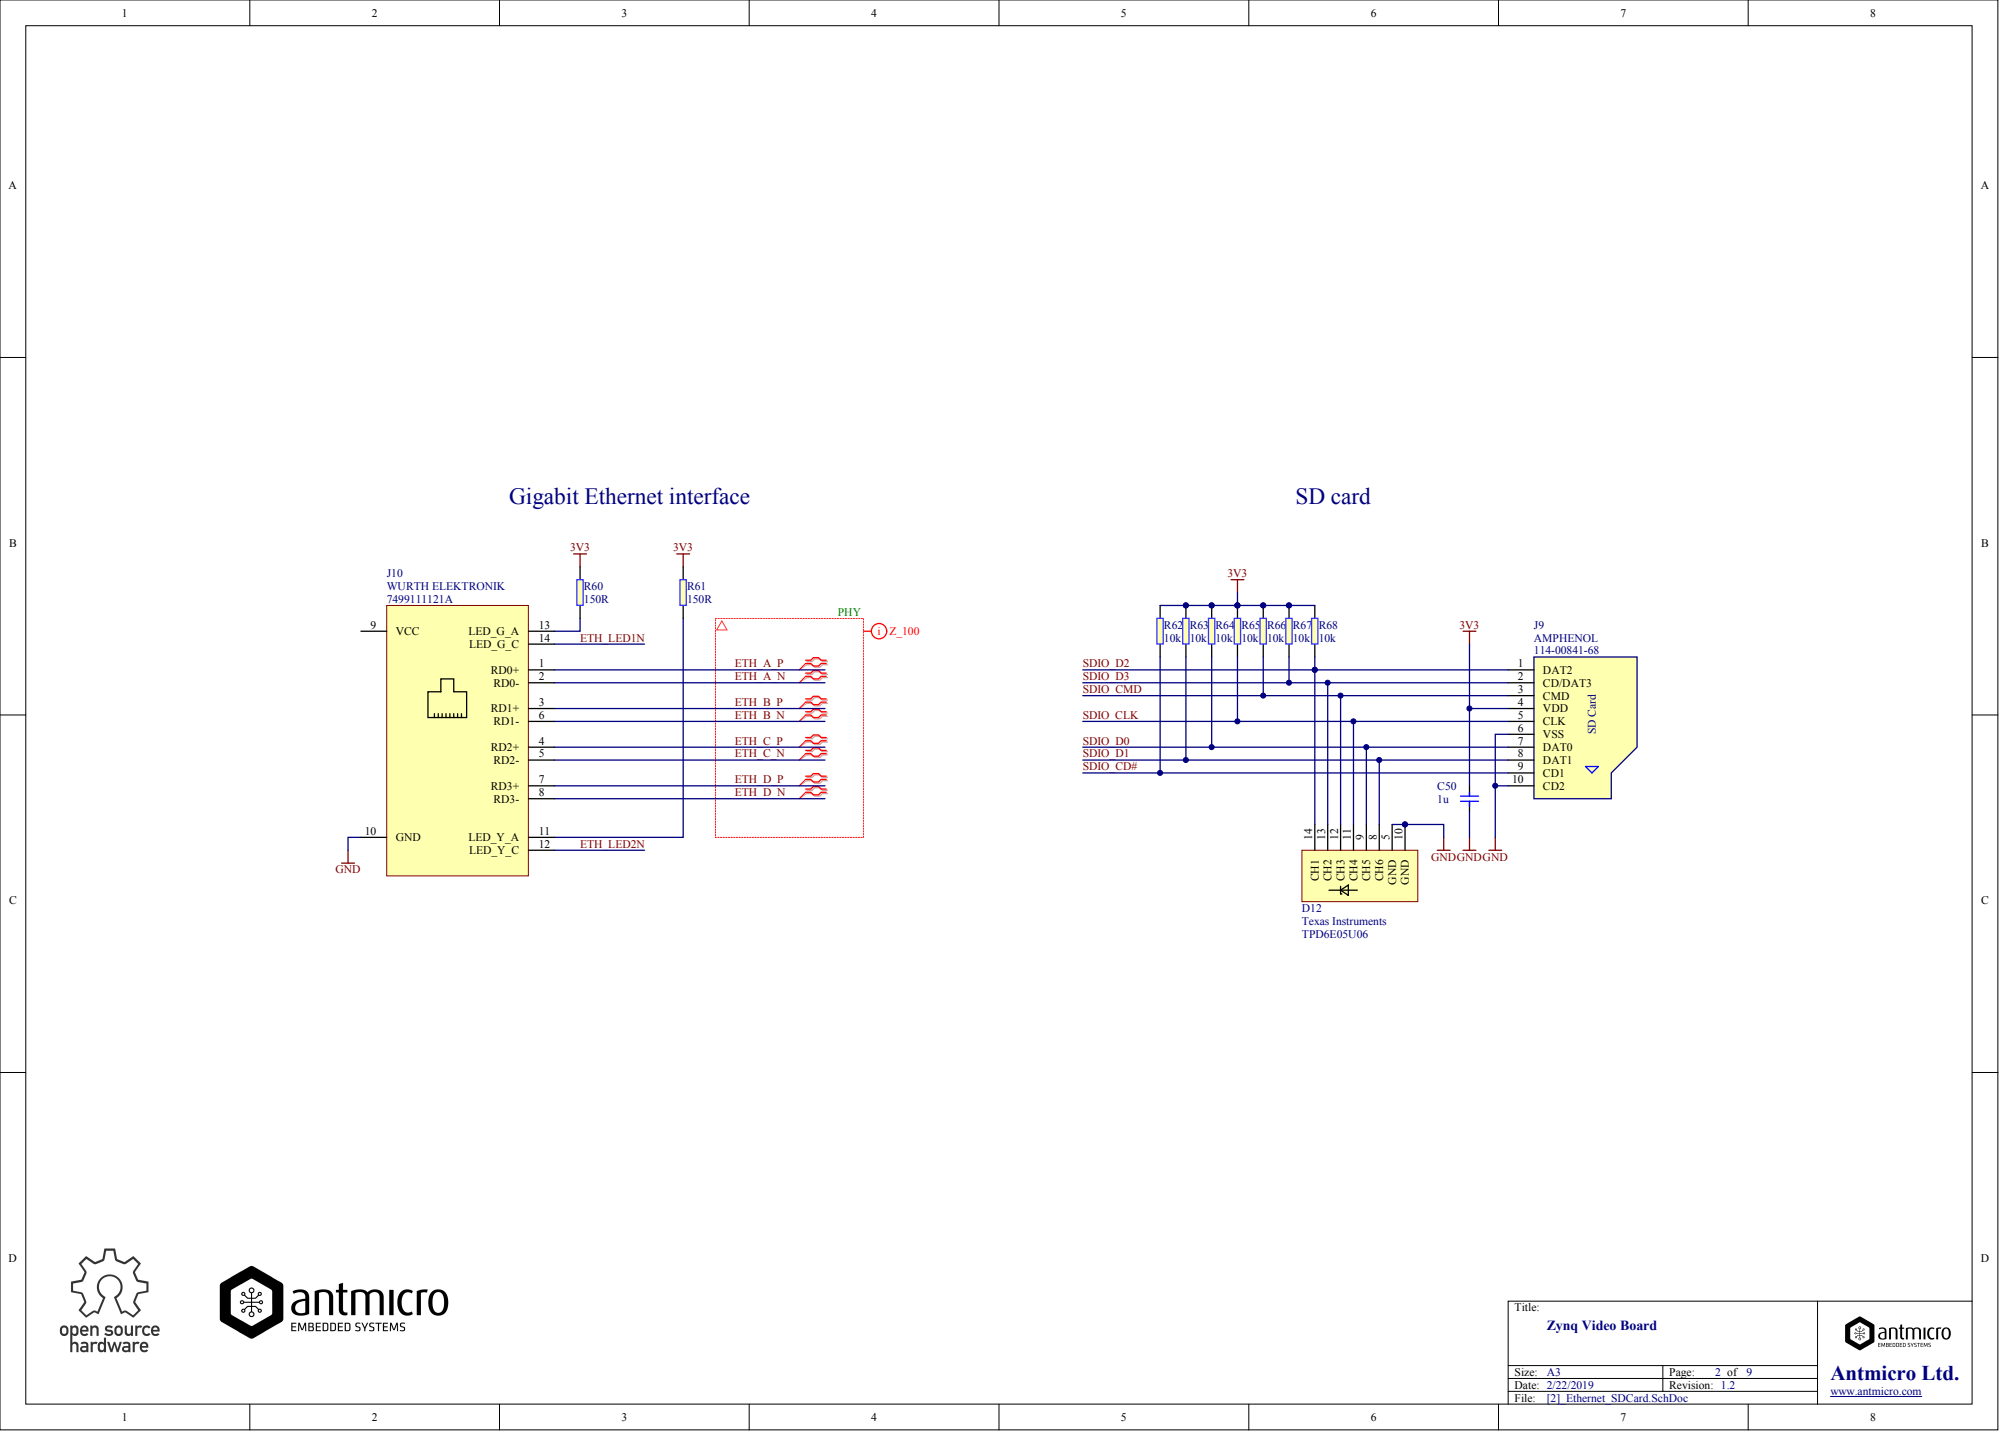
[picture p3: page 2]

Antmicro Ltd. www.antmicro.com

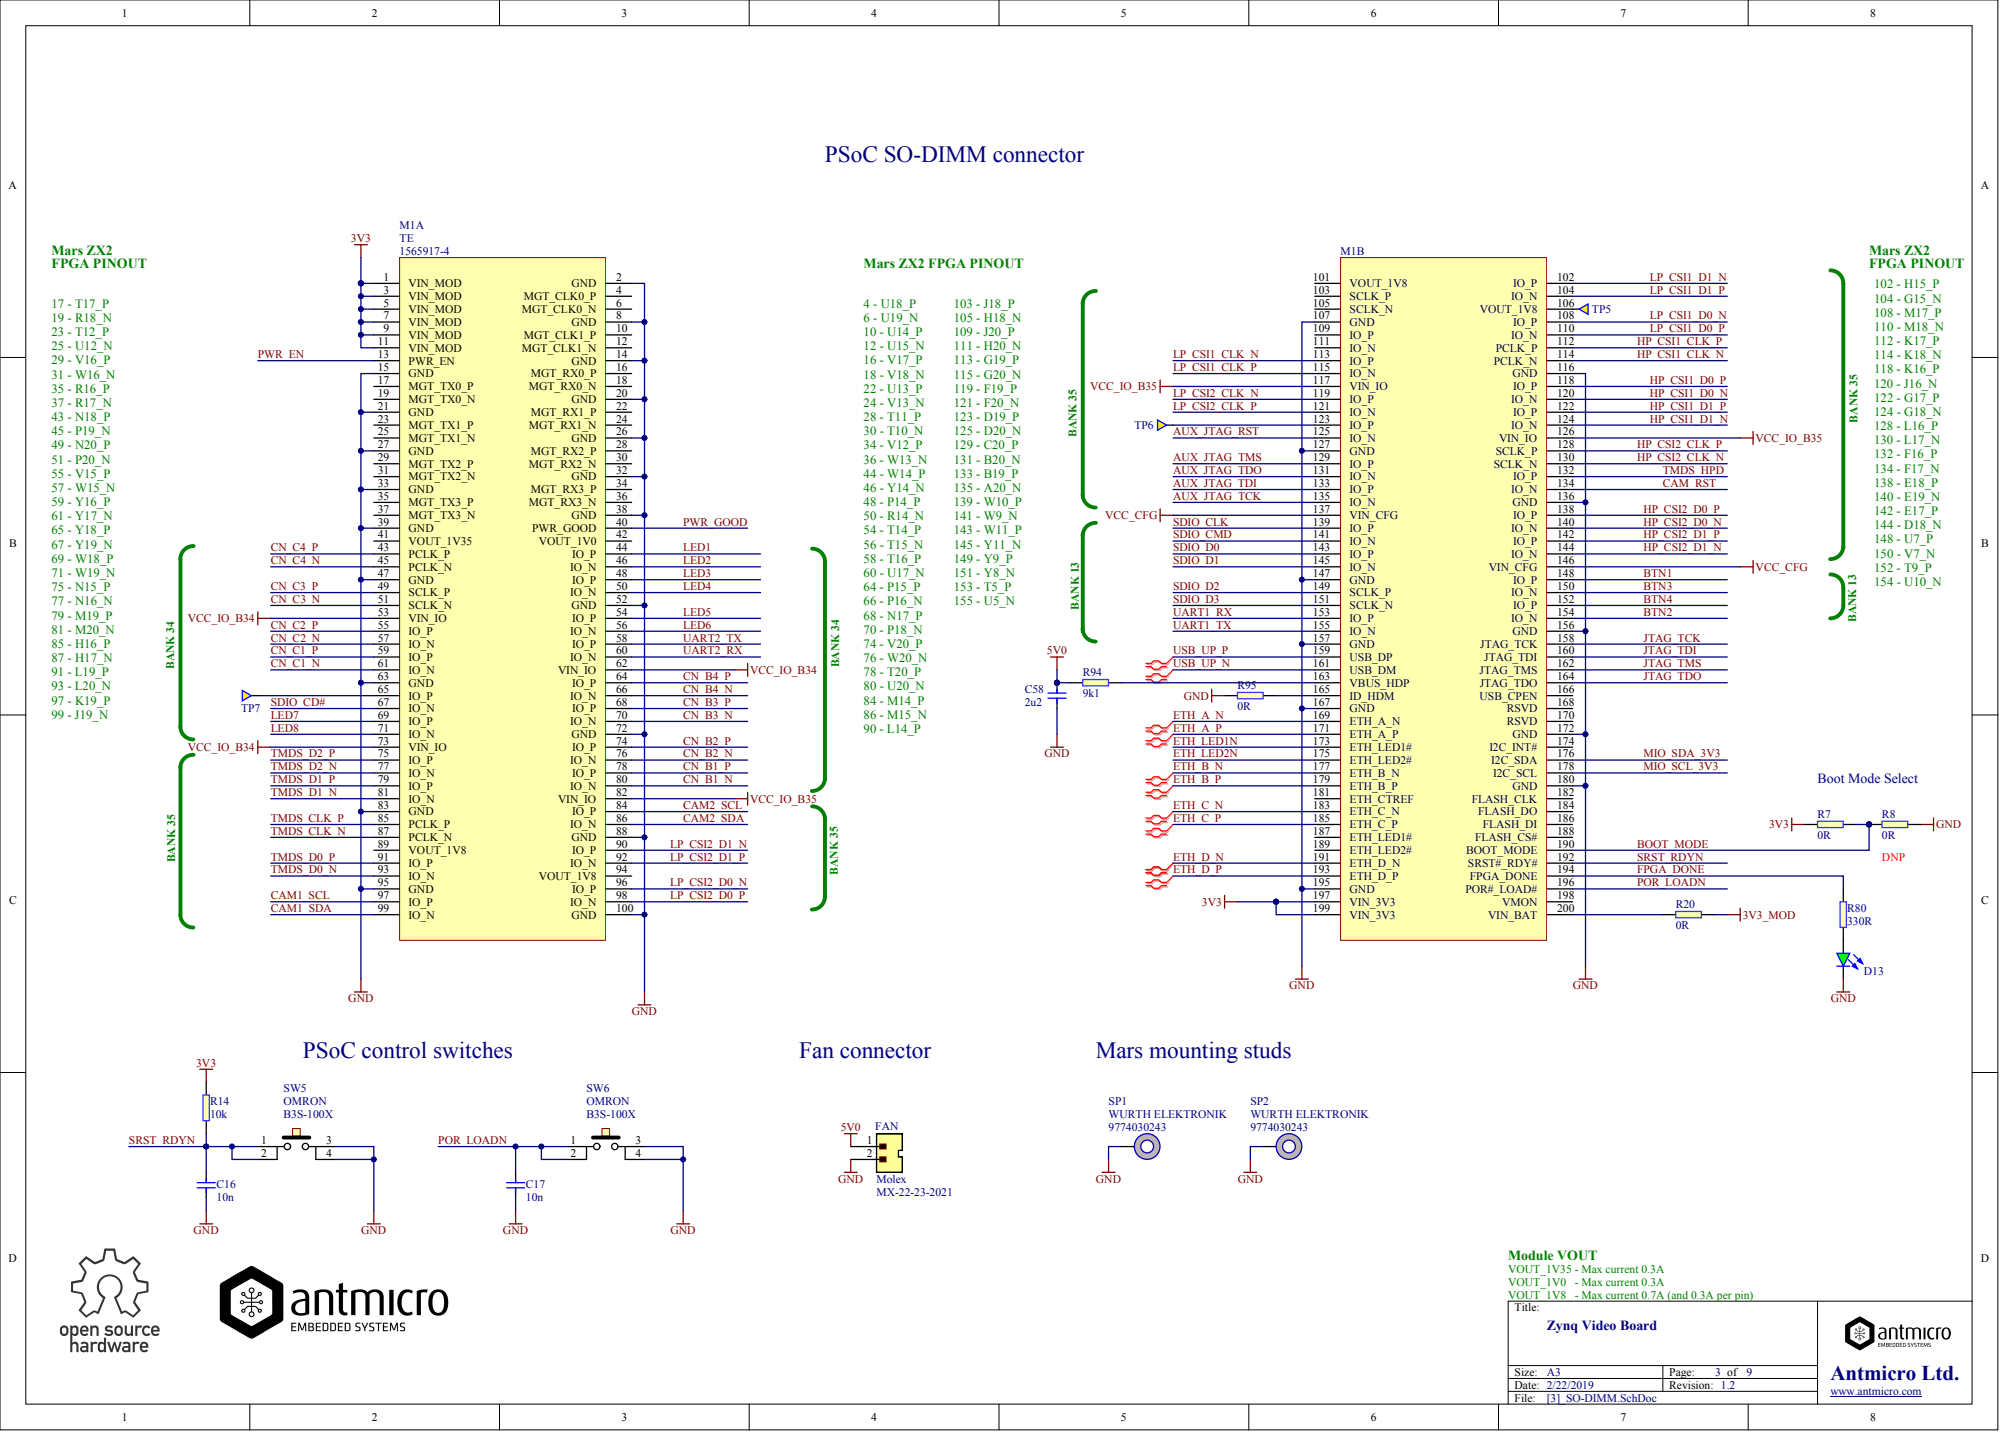
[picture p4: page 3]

PSoC SO-DIMM connector

USB_DP 159 USB_DM 161 VBUS_HDP 163 ID_HDM 165

GND 63 IO_P 65 IO_N 67 IO_P 69 IO_N 71 | CN_B4_N

GND 83 | CN_B2_N

CN_B1_P
CN_B1_N

PCLK_P 85 PCLK_N 87

BOOT_MODE

Module VOUT
VOUT_1V35 - Max current 0.3A
VOUT_1V0 - Max current 0.3A
VOUT_1V8 - Max current 0.7A (and 0.3A per pin)

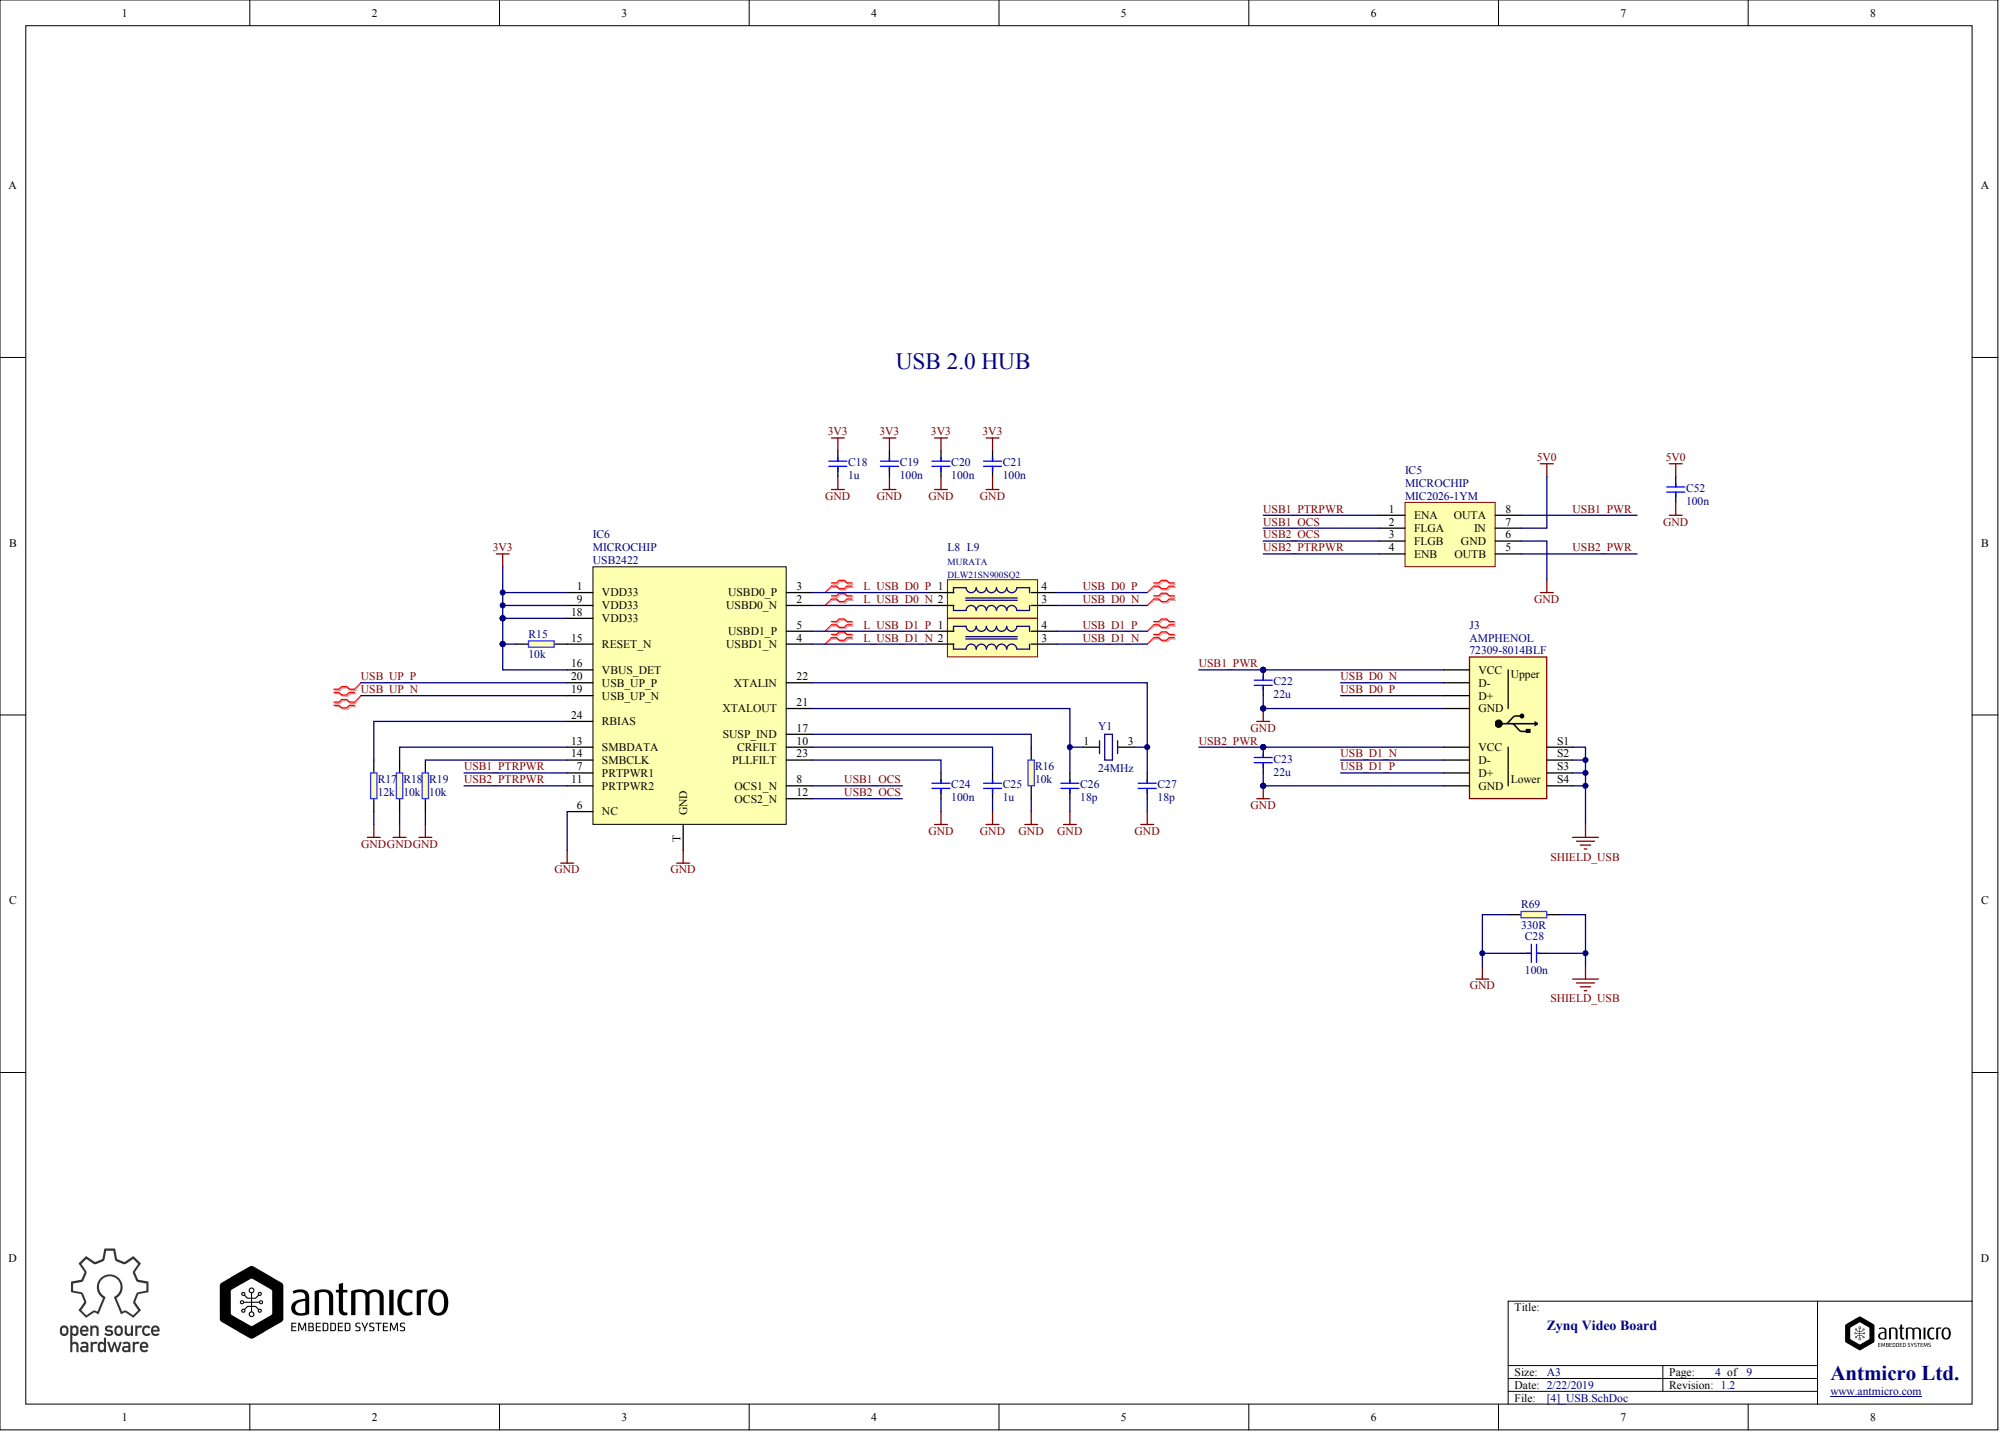
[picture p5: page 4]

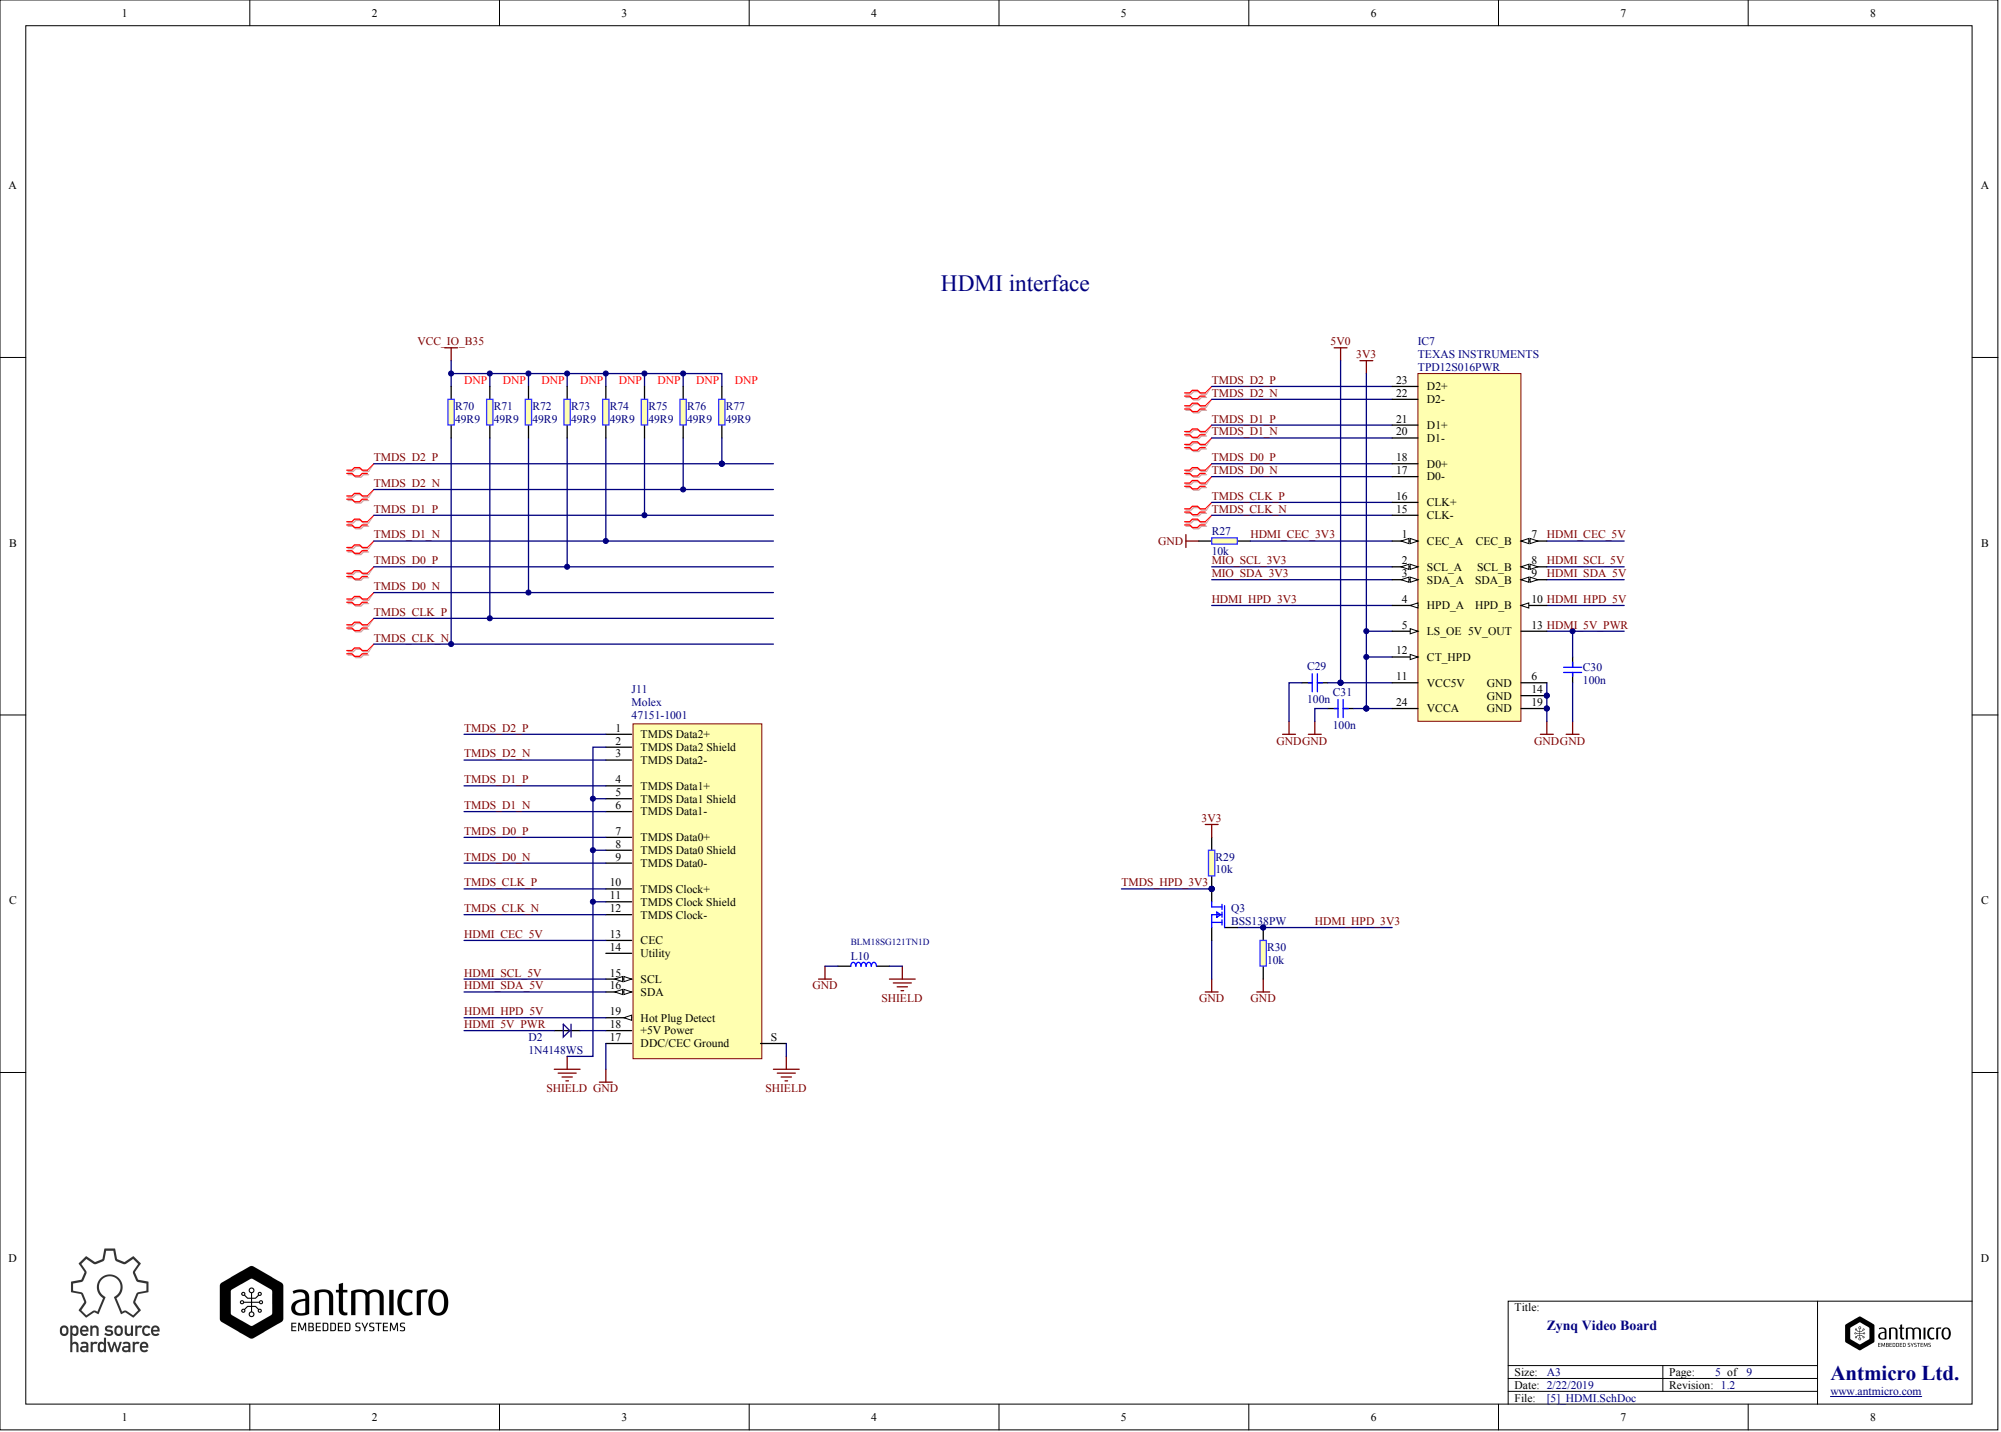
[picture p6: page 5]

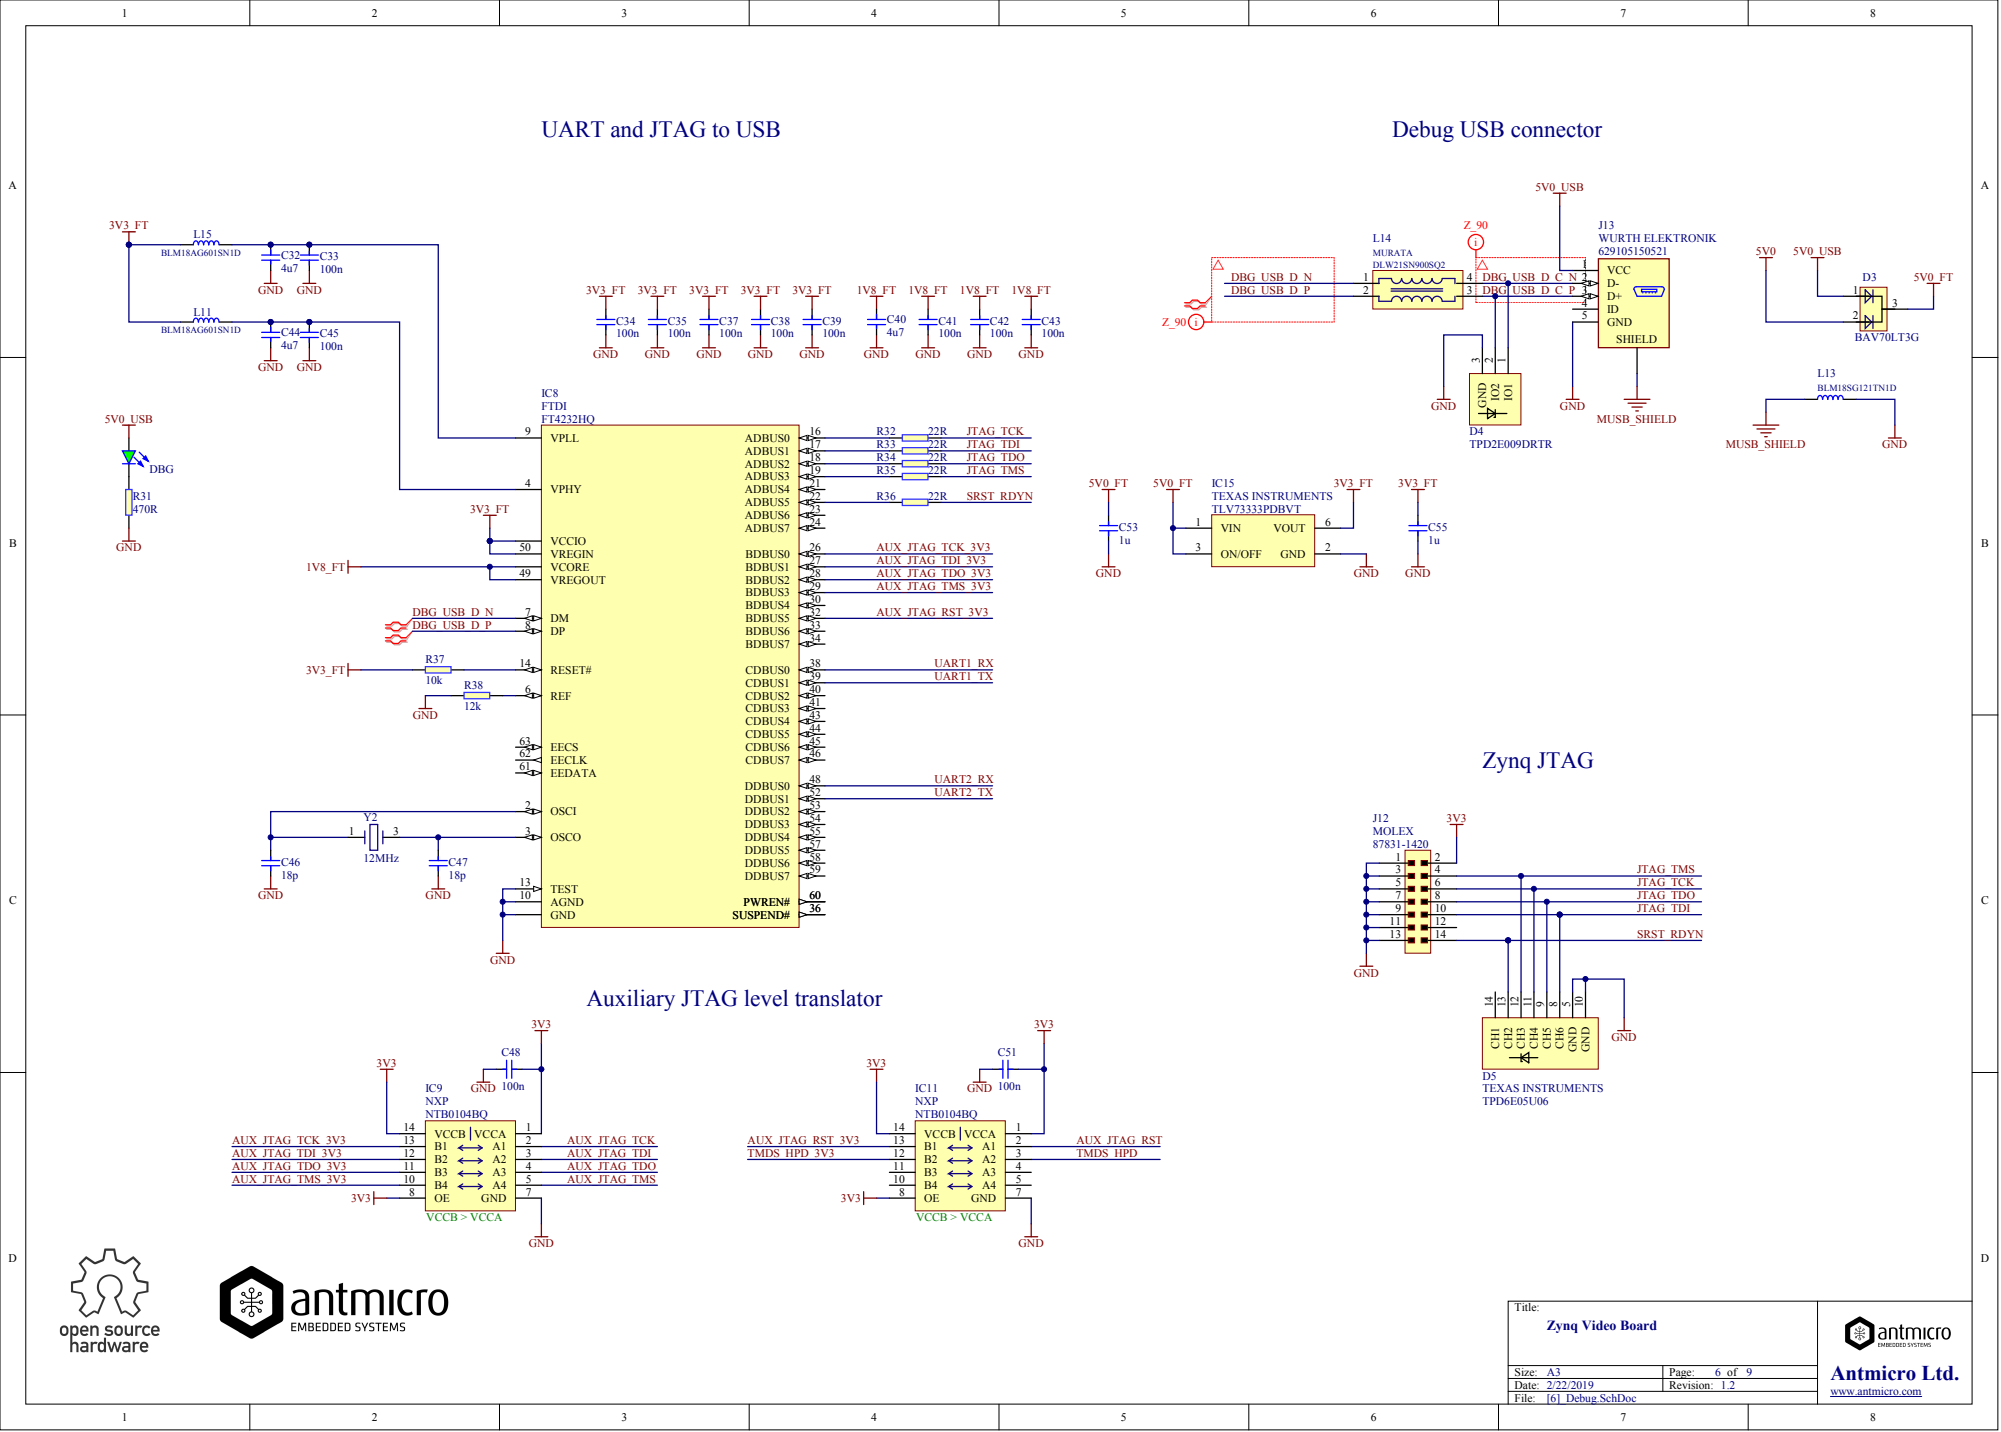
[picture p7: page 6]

UART and JTAG to USB

VPHY 4

VREGIN 50

ON/OFF 3

Auxiliary JTAG level translator

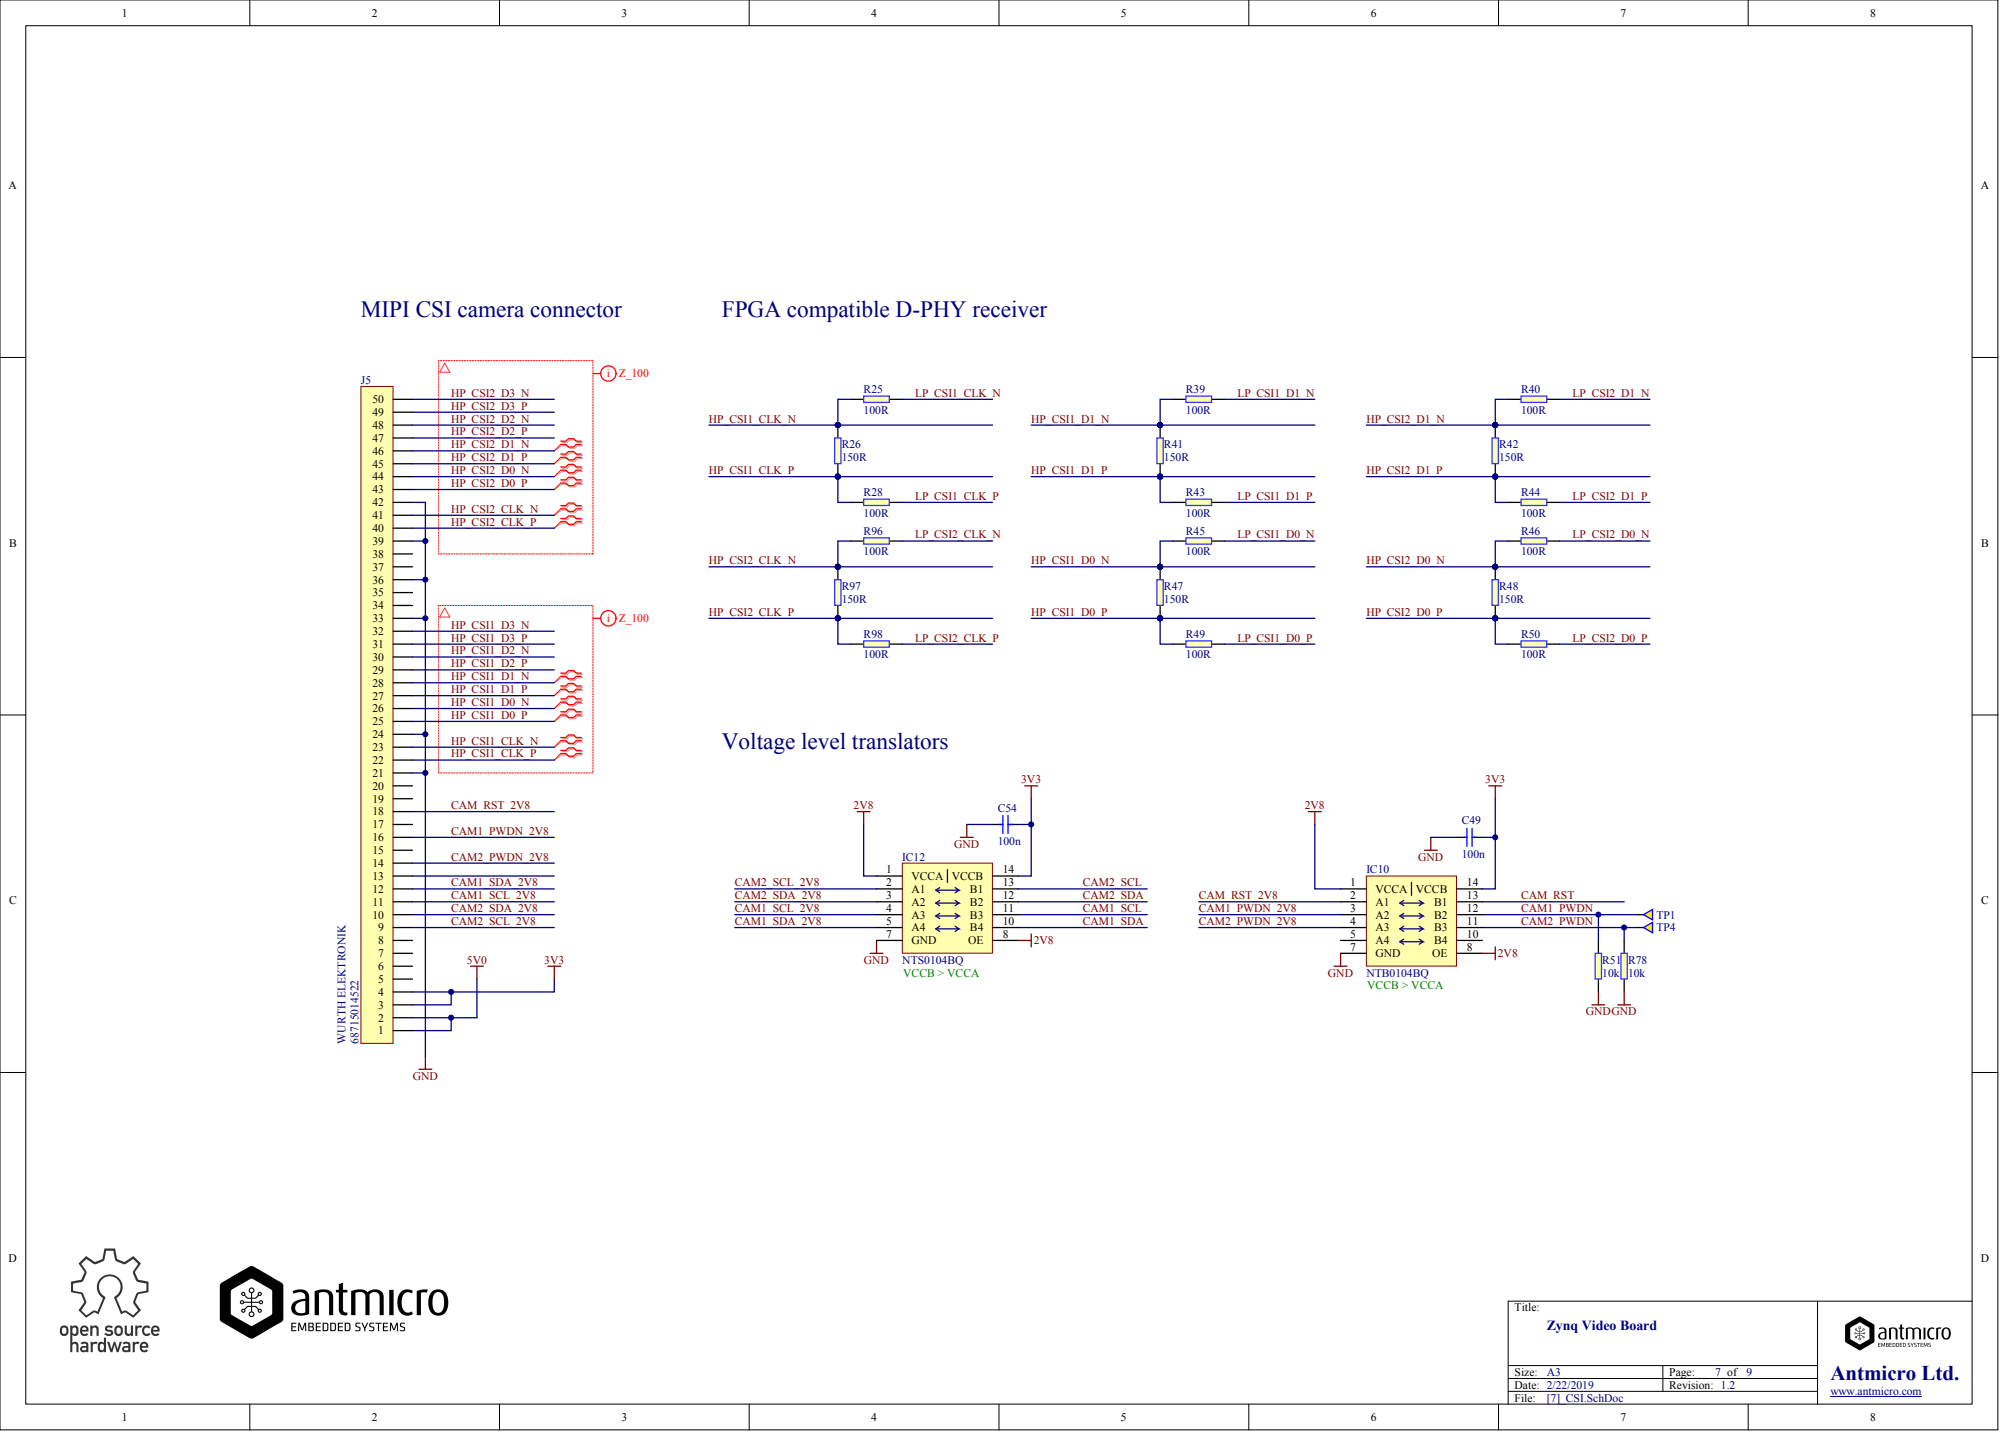
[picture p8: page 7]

MIPI CSI camera connector

FPGA compatible D-PHY receiver
LP_CSI1_CLK_P LP_CSI1_CLK_N LP_CSI2_CLK_P LP_CSI2_CLK_N

HP_CSI1_D3_P
HP_CSI1_D2_N
HP_CSI1_D2_P
HP_CSI1_D1_N
HP_CSI1_D1_P
HP_CSI1_D0_N
HP_CSI1_D0_P

HP_CSI1_CLK_N
HP_CSI1_CLK_P

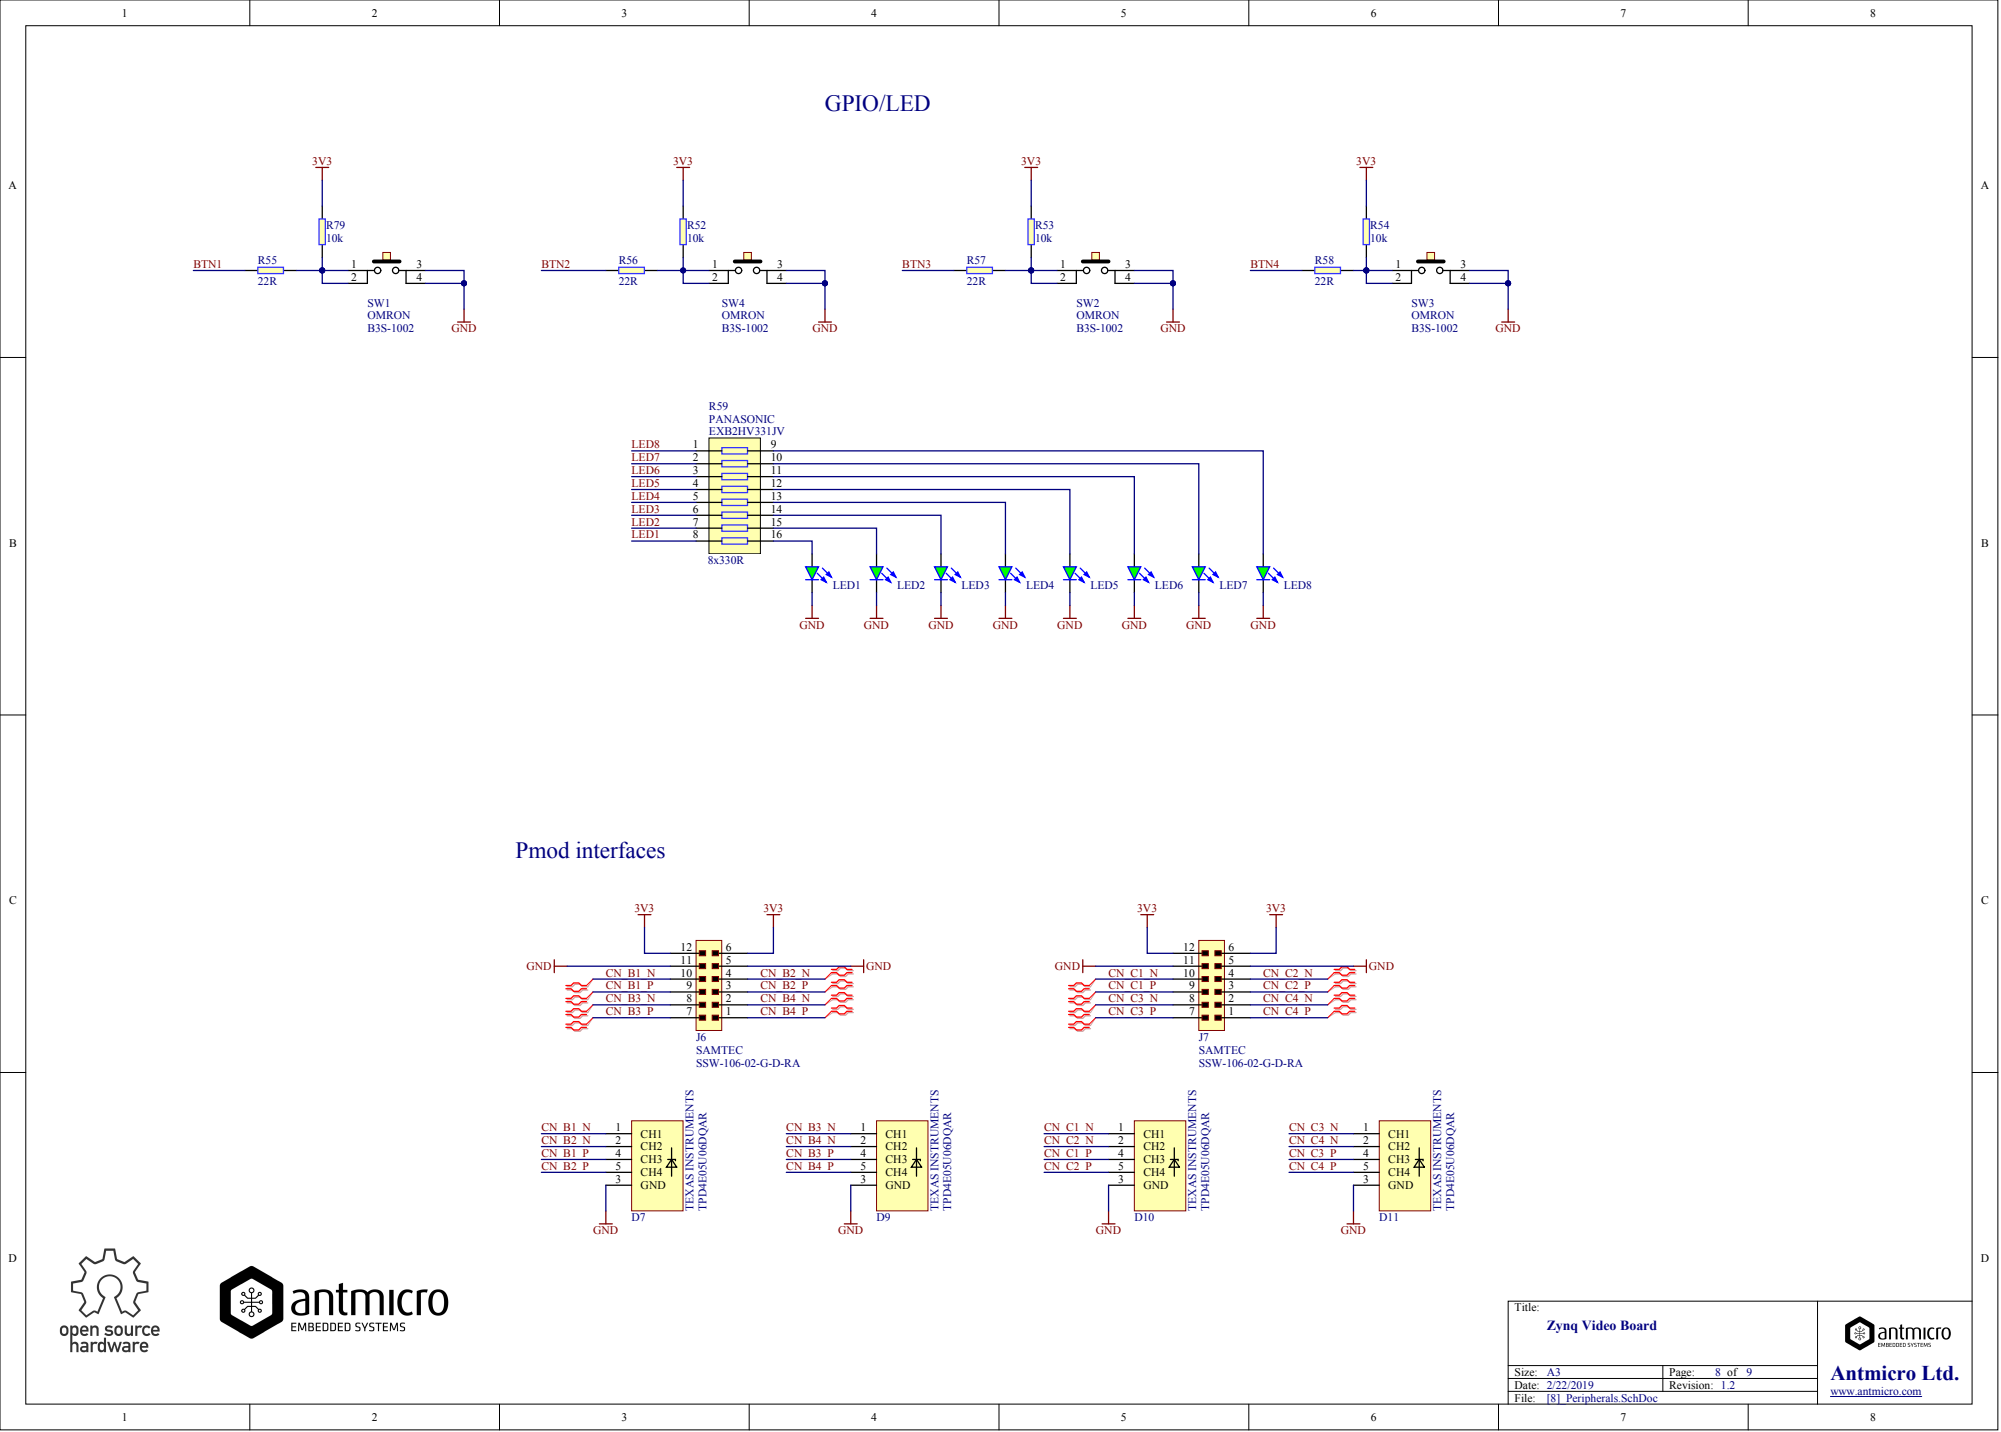
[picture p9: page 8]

10
11
12
13
14
15
16

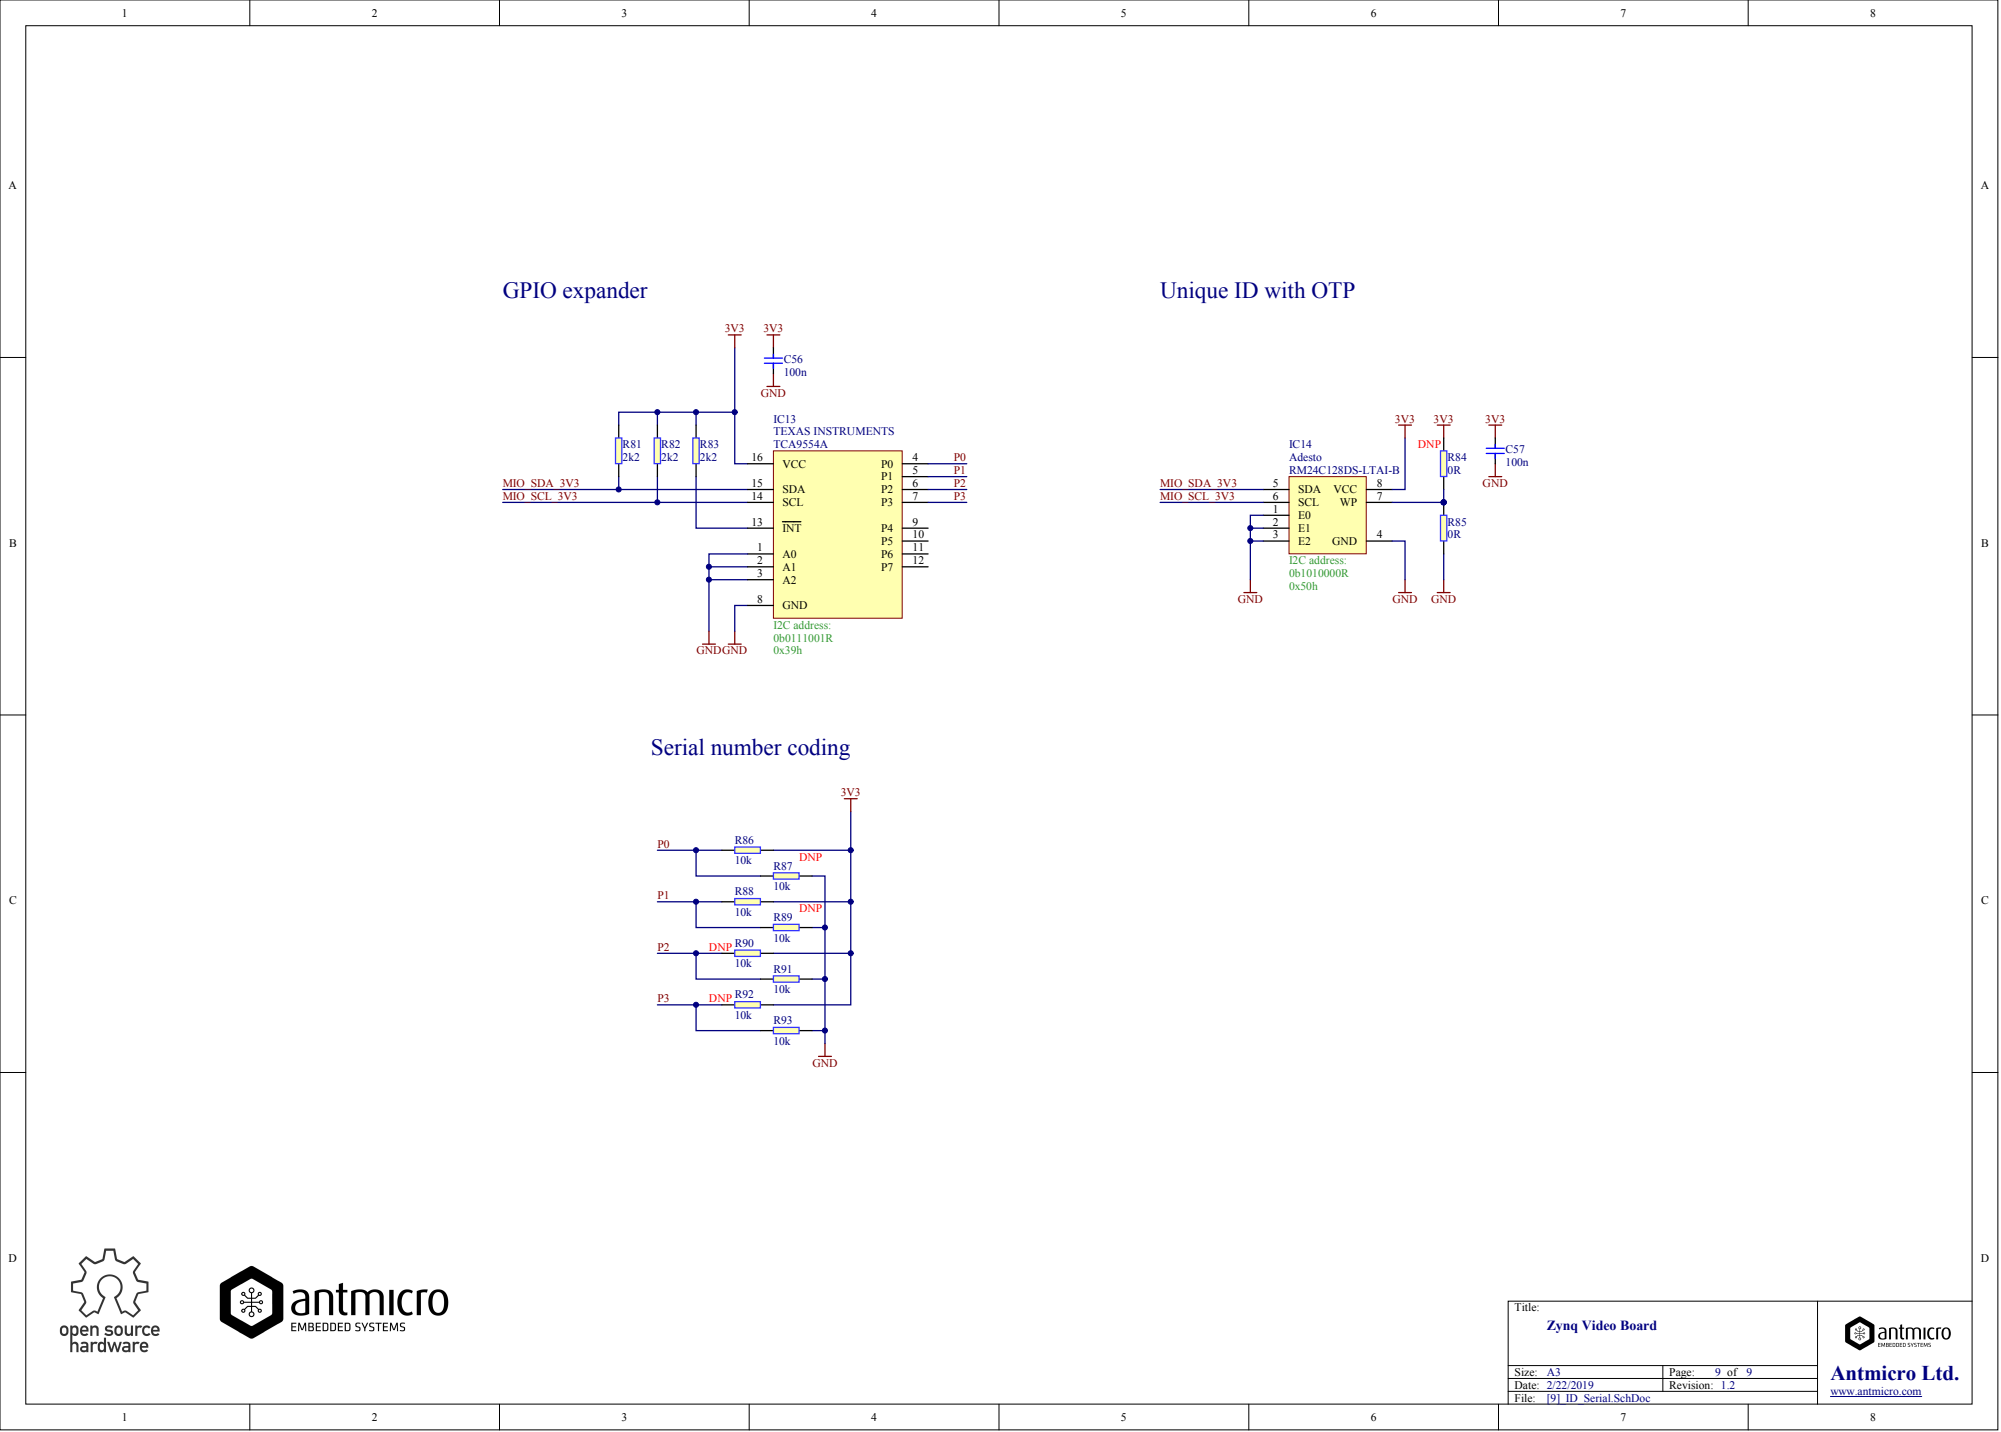
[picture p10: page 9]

Unique ID with OTP

INT 13
